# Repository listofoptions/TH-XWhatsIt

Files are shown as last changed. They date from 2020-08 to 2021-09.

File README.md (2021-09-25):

# TH-XWhatsIt

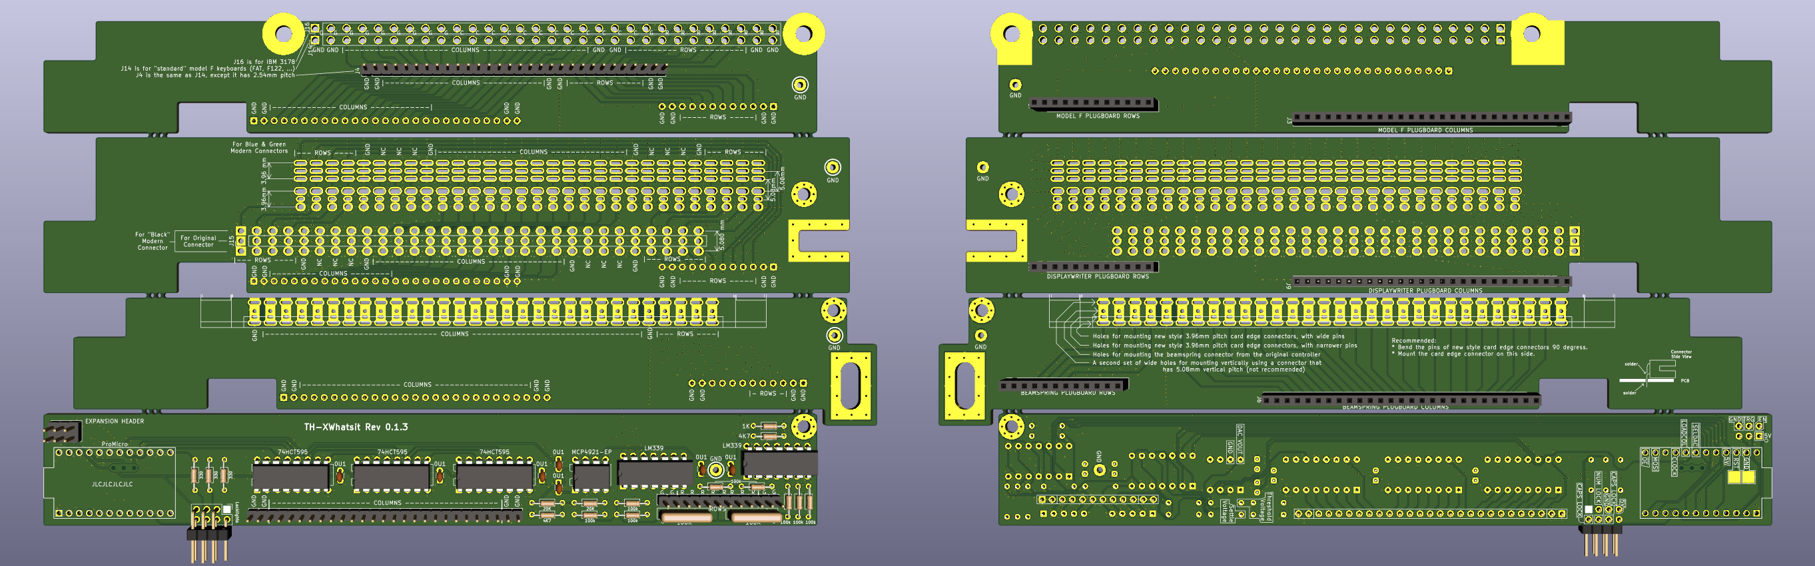
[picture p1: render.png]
Render of the mainboard, and of the plugboards, except the beamship plugboard


through hole implementation of the capsense controllers by XWhatsIt
(Tom Wong-Cornell). original liscencure holds, as well as CERN OSH
(compatible license).

original implementation of Tom Wong-Cornell's controller documented here

http://downloads.cornall.co/ibm-capsense-usb-web/ibm-capsense-usb.html

component documentation is supplied, working theory of operation is under
the previous link.

Please read the following files:

* [BOM.md](BOM.md) for Bill Of Materials.
* [ERRATA.md](ERRATA.md) for changes that must be made to older revision boards.
* [CHANGES.txt](CHANGES.txt) for all the detailed changes to this project over time.
* [PCB_ORDERING_INSTRUCTIONS.md](PCB_ORDERING_INSTRUCTIONS.md) for some notes on how to order PCBs.

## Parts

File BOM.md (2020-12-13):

# Bill Of Materials

## To build 1 pcs of the TH Xwhatsit controller Rev. 0.1.2, you need:

* 1pcs "Pro Micro 5V/16MHz" development board
    * 2pcs male 12-pin header (usually comes included with the Pro Micro)
* 1pcs MCP4921-EP DAC
* 2pcs LM339 comparator
    * (only 1pcs is really needed if the controller will only ever be used on <= 4-row keyboards, such as non-Displaywriter standard beamspring keyboards)
* 3pcs 74AHC595 or 74HCT595 or 74HC595 shift registers
    * (only 2pcs is really needed if the controller will only ever be used on <= 16-column keyboards, such as Model F of Displaywriter keyboards)
* 7pcs 100nF Through Hole Ceramic Capacitors (pin pitch is 2.54mm)
* 1pcs 1K through hole 0.25W resistor (better if subminiature type, metal film)
* 2pcs 20K through hole 0.25W resistors (better if subminiature type, metal film)
* 2pcs 4.7K through hole 0.25W resistors (better if subminiature type, metal film)
* 3pcs 330ohm through hole 0.25W resistors (better if subminiature type, metal film) (new in v0.1.2)
    * Optional if not using lock lights
* 100kohm Resistor Networks, or Resistors, two options:
    * These are recommended to be high precision (1% or 2%), but the design will likely work with 5% resistors too.
    * Option 1: 2pcs 100K 5-pin resistor networks
        * Make sure it's the kind that has a single common pin on one of the sides.
        * (only 1pcs is really needed if the controller will only ever be used on <= 4-row keyboards, such as non-Displaywriter standard beamspring keyboards)
    * Option 2: 8pcs 100K through hole 0.25W resistors (these are the resistors marked with ALT on the PCB)  (better if subminiature type, metal film)
        * (only 4pcs is really needed if the controller will only ever be used on <= 4-row keyboards, such as non-Displaywriter
* 3.96mm 30-pin card edge connectors (if using the controller for Beamspring/Displaywriter keyboards, and if you don't wish to desolder, and reuse the original connector from the original controller PCB)
* M3 standoff, screw, nut, and washers (optional, useful for better mechanical stability with daughterboards)
* 2.54 mm pitch through hole pin headers:
    * Optional if not using Solenoid/Expansion header:
        * 2x3-pin male pinheader (through-hole, can be vertical or 90-degree)
    * Optional if not using lock lights:
        * 2x4-pin male pinheader, (with 1 pin manually removed) (through-hole, can be vertical or 90-degree)
    * Optional if soldering wires directly to the motherboard, and not using the daughtercards:
        * male 27-pin pinheader (straight, through hole)
        * female 27-pin pinheader (straight, through hole)
        * male 12-pin pinheader (straight, through hole)
        * female 12-pin pinheader (straight, through hole)
    * You can buy pinheaders with more pins then necessary, and cut them. You can use two 1-row pin headers to make a vertical Solenoid connector.

## Notes regarding older revisions:

* Previous revisions can't fit an M3 standoff, so you have to get an M2 standoff
* Combining daughtercard/motherboard from different revisions is possible, (the pin headers are in the same relative positions), but the hole that can be used for a standoff is in a slightly different position, so if combining you can't use standoffs
* 10Kohm resistor networks, present in previous revisions are optional, they don't need to be mounted even if using a previous-revision board.
* the 10uF capacitor which was present in the first version of the TH MUST NOT be mounted.
* Only one pair of 1K, 4.7k resistors is necessary to set the BIAS voltage. Some previous TH versions had two pairs. It is okay to only mount one pair, or to mount both pairs, but the two bias points must be connected for >4-row keyboards.
* Previous versions supported fewer card edge connector types when using them for Beamspring/Displaywriter keyboards.

## Octopart BOM:

An octopart BOM has been assembled here: [link](https://octopart.com/bom-tool/UL7oTH6f)

## TME quick buy - uploading products from a file:

* [Go to this URL](https://www.tme.eu/ro/en/Profile/QuickBuy/load.html)
* Click "Uploading products from a file"
* Select "csv"
* Select [tme_bom.csv](tme_bom.csv) from this folder.
* Click Upload
* Click Add to Order
* Note: quantities have been adjusted for minimum order amounts.

## Individual links to various sources

All links in this document may become out of date. They may become unavailable, or price changes may make them not be good options anymore. Please do your own research before committing to buy.

* Pro Micro 5V/16MHz
    * Sparkfun Pro Micro: [link](https://www.sparkfun.com/products/12640)
        * More on the pricier side, but Sparkfun designed the Pro Micro, so they are probably the highest quality source.
        * They also have many distributors: [link](https://www.sparkfun.com/distributors)
          * The original Sparkfun Pro Micro is also available from these distributors:
            * Digikey: Digi-Key Part Number: [1568-1060-ND](https://www.digikey.com/en/products/detail/DEV-12640/1568-1060-ND/5140825)
            * Mouser: Mouser No: [474-DEV-12640](https://eu.mouser.com/ProductDetail/SparkFun/DEV-12640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)
    * Aliexpress:
        * There are many sellers on [aliexpress.com](https://www.aliexpress.com), the best deals are often for bulk quantities, but not always
        * Examples:
            * [link](https://www.aliexpress.com/item/4000087265549.html) (EDIT they recently raised their prices, cheaper may be available)
    * Ebay:
        * Also many sellers, examples:
            * [link](https://www.ebay.co.uk/itm/Pro-Micro-ATmega32U4-5V-16MHz-Replace-ATmega328-Pro-Mini-for-Arduino/283659748382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)
            * [link](https://www.ebay.co.uk/itm/Arduino-Pro-Micro-ATmega32U4-MU-5V-16MHz-Leonardo-Compatible-Board/183467795511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)
            * [link](https://www.ebay.co.uk/itm/Arduino-Pro-Micro-ATmega32U4-AU-5V-16MHz-Leonardo-Compatible-Board/183467793639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) - this is a less-then usual 'square' version where the microcontroller is in a TQFP package.
    * Alternatives, that are not exactly pro micro:
        * Sparkfun qwiic pro USB-C (not tested): [link](https://www.sparkfun.com/products/15795)
    * DO NOT BUY:
        * Don't buy 3V/8MHz Pro Micros, they are not supported.
        * Don't buy "DM DIY MORE" Pro Micros -- these are wider then most other pro micros, and won't physically fit [link](https://www.ebay.co.uk/itm/ATMEGA32U4-Pro-Micro-3-3V-5V-8-16MHz-USB-Controller-Board-Bootloader-for-Arduino/153425765054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)
        * Don't buy Proton-C, because non-AVR cores are not supported by my firmware. [link](https://qmk.fm/proton-c/)
        * *Maybe* do not buy Pro Micro drop-in replacements, that use DFU bootloader. These can be supported, but only if you compile your firmware locally. Otherwise many bootloader entry methods will not work. You also have the option of replacing the bootloader on one of these with ISP programming. Example: [Elite-C](https://keeb.io/products/elite-c-low-profile-version-usb-c-pro-micro-replacement-atmega32u4)
* Card Edge Connector (For beamsprings/displaywriters)
    * You can use the original connector, desoldered from the original controller
    * Please read this [thread](https://deskthority.net/viewtopic.php?f=7&t=24511&p=473024&hilit=tightness#p473024)
    * EDAC connector sources: (I recommend pin-modding these)
      * Higher pin-count, must be cut, but the extra pins are useful if pin-modding: 
        * Digikey: Digi-Key Part Number: [151-1359-ND](https://www.digikey.com/en/products/detail/307-086-520-202/151-1359-ND/1292373)
        * Mouser: Mouser No: [587-307-086-520-202](https://eu.mouser.com/ProductDetail/EDAC/307-086-520-202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)
      * TME: Not a great option, you can buy two of these lower-pin-count connectors, and cut both, and put them next to each other: TME Symbol: [307-030-520-202](https://www.tme.eu/ro/en/details/307-030-520-202/idc-connectors/edac/)
* MCP4921-E/P DAC:
    * TME: TME Symbol: [MCP4921-E/P](https://www.tme.eu/ro/en/details/mcp4921-e_p/d-a-converters-integrated-circuits/microchip-technology/)
    * LCSC: Last checked it wasn't available in a DIP package. 15 nov. 2020. LCSC Part # [C640392](https://lcsc.com/product-detail/Pre-ordered-Products_Microchip-Tech_MCP4921-E-P_Microchip-Tech-MCP4921-E-P_C640392.html)
    * Digikey: Digi-Key Part Number: [MCP4921-E/P-ND](https://www.digikey.com/en/products/detail/MCP4921-E-P/MCP4921-E-P-ND/716280)
    * Mouser: Mouser No: [579-MCP4921-E/P](https://eu.mouser.com/ProductDetail/Microchip-Technology/MCP4921-E-P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)
* 74*595 Shift Register:
    * TME: TME Symbol: [SN74HC595N](https://www.tme.eu/ro/en/details/sn74hc595n/shift-registers/texas-instruments/)
    * LCSC: LCSC Part # [C112387](https://lcsc.com/product-detail/74-Series_Wuxi-I-core-Elec-AIP74HC595-DIP_C112387.html)
    * Digikey: Digi-Key Part Number: [296-1600-5-ND](https://www.digikey.com/en/products/detail/texas-instruments/SN74HC595N/277246)
    * Mouser: Mouser No: [595-SN74HC595N](https://eu.mouser.com/ProductDetail/Texas-Instruments/SN74HC595N?qs=IEl3ej0IqwBTHkYa8XPoMQ%3D%3D)
* LM339 Comparator:
    * TME: TME Symbol: [LM339N/NOPB](https://www.tme.eu/ro/en/details/lm339n_nopb/tht-comparators/texas-instruments/)
    * LCSC: LCSC Part # [C127024](https://lcsc.com/product-detail/Analog-Comparators_UTC-Unisonic-Tech-LM339L-D14-T_C127024.html)
    * Digikey: Digi-Key Part Number: [296-39010-5-ND](https://www.digikey.com/en/products/detail/LM339N-NOPB/296-39010-5-ND/4733938)
    * Mouser: Mouser No: [926-LM339N/NOPB](https://eu.mouser.com/ProductDetail/Texas-Instruments/LM339N-NOPB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)
* 100nF Through Hole Ceramic Capacitors:
    * TME: TME Symbol: [CC-100N](https://www.tme.eu/ro/en/details/cc-100n/50v-tht-ceramic-capacitors/sr-passives/)
    * LCSC: LCSC Part # [C154503](https://lcsc.com/product-detail/Multilayer-Ceramic-Capacitors-MLCC-Leaded_FH-Guangdong-Fenghua-Advanced-Tech-CT4-0805Y104M500F1_C154503.html)
    * Digikey: Digi-Key Part Number: [399-4329-ND](https://www.digikey.com/en/products/detail/C322C104K5R5TA/399-4329-ND/818105)
    * Mouser: Mouser No: [80-C322C104K5R](https://eu.mouser.com/ProductDetail/KEMET/C322C104K5R5TA?qs=XvIqZs20p47gvrtGJkxvnw%3D%3D)
* 1K resistors:
    * TME variants:
      * TME Symbol: [M0.4W-1K](https://www.tme.eu/ro/en/details/m0.4w-1k/0-4w-metal-film-tht-resistors/royal-ohm/mff04ff1001a5/)
      * TME Symbol: [MF0204FTE52-1K](https://www.tme.eu/ro/en/details/mf0204fte52-1k/0-4w-metal-film-tht-resistors/yageo/mf0204fte52-1kl/)
      * TME Symbol: [MBA02040C1001FCT00](https://www.tme.eu/ro/en/details/mba02040c1001fct00/0-4w-metal-film-tht-resistors/vishay/)
      * TME Symbol: [MRS16000C1001FCT00](https://www.tme.eu/ro/en/details/mrs16000c1001fct00/0-4w-metal-film-tht-resistors/vishay/)
    * LCSC: LCSC Part # [C433503](https://lcsc.com/product-detail/Metal-Film-Resistor-TH_TyoHM-RN-1-8W-1K-F-T-B-A1_C433503.html)
    * Digikey: Digi-Key Part Number: [PPC1.00KXCT-ND](https://www.digikey.com/en/products/detail/SFR16S0001001FR500/PPC1.00KXCT-ND/594732)
    * Mouser: Mouser No: [594-SFR16S0001001FR5](https://eu.mouser.com/ProductDetail/Vishay-BC-Components/SFR16S0001001FR500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)
* 20K resistors:
    * TME variants:
      * TME Symbol: [MBA02040C2002FC100](https://www.tme.eu/ro/en/details/mba02040c2002fc100/0-4w-metal-film-tht-resistors/vishay/)
      * TME Symbol: [M0.4W-20K](https://www.tme.eu/ro/en/details/m0.4w-20k/0-4w-metal-film-tht-resistors/royal-ohm/mff04ff2002a5/)
    * LCSC: LCSC Part # [C433488](https://lcsc.com/product-detail/Metal-Film-Resistor-TH_TyoHM-RN-1-8W-20K-F-T-B-A1_C433488.html)
    * Digikey: Digi-Key Part Number: [PPC20.0KXCT-ND](https://www.digikey.com/en/products/detail/SFR16S0002002FR500/PPC20.0KXCT-ND/594752)
    * Mouser: Mouser No: [594-SFR16S0002002FR5](https://eu.mouser.com/ProductDetail/Vishay-BC-Components/SFR16S0002002FR500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)
* 4.7K resistors:
    * TME variants:
      * TME Symbol: [MBA02040C4701FCT00](https://www.tme.eu/ro/en/details/mba02040c4701fct00/0-4w-metal-film-tht-resistors/vishay/)
      * TME Symbol: [MF0204FTE52-4K7](https://www.tme.eu/ro/en/details/mf0204fte52-4k7/0-4w-metal-film-tht-resistors/yageo/mf0204fte52-4k7l/)
      * TME Symbol: [MRS16000C4701FC100](https://www.tme.eu/ro/en/details/mrs16000c4701fc100/0-4w-metal-film-tht-resistors/vishay/)
      * TME Symbol: [M0.4W-4K7](https://www.tme.eu/ro/en/details/m0.4w-4k7/0-4w-metal-film-tht-resistors/royal-ohm/mff04ff4701a5/)
    * LCSC: LCSC Part # [C433477](https://lcsc.com/product-detail/Metal-Film-Resistor-TH_TyoHM-RN-1-8W-4K7-F-T-B-A1_C433477.html)
    * Digikey: Digi-Key Part Number: [BC3275CT-ND](https://www.digikey.com/en/products/detail/MBA02040C4701FCT00/BC3275CT-ND/6138778)
    * Mouser: Mouser No: [594-5063JD4K700F5](https://eu.mouser.com/ProductDetail/Vishay-Beyschlag/MBA02040C4701FCT00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)
* 330ohm resistors:
    * TME variants:
      * TME Symbol: [MBA02040C3300FCT00](https://www.tme.eu/ro/en/details/mba02040c3300fct00/0-4w-metal-film-tht-resistors/vishay/)
      * TME Symbol: [MRS16000C3300FCT00](https://www.tme.eu/ro/en/details/mrs16000c3300fct00/0-4w-metal-film-tht-resistors/vishay/)
      * TME Symbol: [M0.4W-330R](https://www.tme.eu/ro/en/details/m0.4w-330r/0-4w-metal-film-tht-resistors/royal-ohm/mff04ff3300a50/)
    * LCSC: LCSC Part # [C433480](https://lcsc.com/product-detail/Metal-Film-Resistor-TH_TyoHM-RN-1-8W-330R-F-T-B-A1_C433480.html)
    * Digikey: Digi-Key Part Number: [BC3933CT-ND](https://www.digikey.com/en/products/detail/vishay-beyschlag-draloric-bc-components/MRS16000C3300FCT00/7351363)
    * Mouser: Mouser No: [594-5063JD330R0F](https://eu.mouser.com/ProductDetail/Vishay-Beyschlag/MBA02040C3300FC100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)
* 100kohm resistor networks (either get the resistor networks, or individual resistors, not both):
    * TME variants:
      * TME Symbol for 2% precision resistor network (was out of stock on 15 nov. 2020): [4605X-101-104LF](https://www.tme.eu/ro/en/details/4605x-101-104lf/tht-resistor-networks/bourns/)
      * TME Symbol for 2% precision resistor network: [DR100K-4/5](https://www.tme.eu/ro/en/details/dr100k-4_5/tht-resistor-networks/royal-ohm/rnla05g0104b0e/)
    * LCSC variants:
      * LCSC Symbol for 5% precision resistor network: [C11398](https://lcsc.com/product-detail/Resistor-Networks-Arrays_FH-Guangdong-Fenghua-Advanced-Tech-A05-104JP_C11398.html)
        * ^ This one is not really recommended, too low precision, it would probably work, but better find higher precision resistor network, or use individual resistors.
      * LCSC Symbol for 2% precision resistor network (was out of stock on 15 nov. 2020): [C353644](https://lcsc.com/product-detail/Resistor-Networks-Arrays-TH_ZHUHAI-MONEC-ELEC-RAA05104G_C353644.html)
* 100kohm individual resistors (either get the resistor networks, or individual resistors, not both):
    * TME variants:
      * TME Symbol for 1% precision individual resistors: [MBA02040C1003FCT00](https://www.tme.eu/ro/en/details/mba02040c1003fct00/0-4w-metal-film-tht-resistors/vishay/)
      * TME Symbol for 1% precision individual resistors: [MF0204FTE52-100K](https://www.tme.eu/ro/en/details/mf0204fte52-100k/0-4w-metal-film-tht-resistors/yageo/mf0204fte52-100kl/)
      * TME Symbol for 1% precision individual resistors: [M0.4W-100K](https://www.tme.eu/ro/en/details/m0.4w-100k/0-4w-metal-film-tht-resistors/royal-ohm/mff04ff1003a5/)
    * LCSC Symbol for 1% precision individual resistors: [C433501](https://lcsc.com/product-detail/Metal-Film-Resistor-TH_TyoHM-RN-1-8W-100K-F-T-B-A1_C433501.html)
    * Digikey: Digi-Key Part Number: [PPC100KXCT-ND](https://www.digikey.com/en/products/detail/SFR16S0001003FR500/PPC100KXCT-ND/594692)
    * Mouser: Mouser No: [594-SFR16S0001003FR5](https://eu.mouser.com/ProductDetail/Vishay-BC-Components/SFR16S0001003FR500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)
* M3 standoff/screw/washer:
    * TME:
        * 10mm M3 standoff: TME Symbol: [TFF-M3X10/DR113](https://www.tme.eu/ro/en/details/tff-m3x10_dr113/metal-spacers/dremec/113x10/)
        * 0.5mm height 6mm external diameter M3 washers to fine adjust spacing: TME Symbol: [B3/6/0.5/BN1976](https://www.tme.eu/ro/en/details/b3_6_0.5_bn1976/washers/bossard/m3-6-0-5-bn1976-din988/)
            * you will need to use two 0.5mm height washers, so the total height will be 10mm + 2*0.5mm = 11mm. This matches the total height of the plastic parts of the pin headers, which is 8.5mm + 2.5mm = 11mm.
        * 5mm long M3 screws: TME Symbol: [B3X5/BN2724](https://www.tme.eu/ro/en/details/b3x5_bn2724/screws/bossard/m3x5-bn2724/)
    * Digikey:
        * 11mm M3 standoff: Digi-Key Part Number: [732-10550-ND](https://www.digikey.com/en/products/detail/970110321/732-10550-ND/6174770)
        * Digi-Key Part Number: [36-9191-4-ND](https://www.digikey.com/en/products/detail/9191-4/36-9191-4-ND/4499485)
    * Mouser:
        * 11mm M3 standoff: Mouser No: [710-970110321](https://eu.mouser.com/ProductDetail/Wurth-Elektronik/970110321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)
        * Mouser No: [534-9191-4](https://eu.mouser.com/ProductDetail/Keystone-Electronics/9191-4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)
    * Aliexpres:
      * 910pcs/set M3 Male Female Hex Brass Standoff Spacer with Pan Head Screw Nut and Washer Assortment Kit: [link](https://www.aliexpress.com/item/4001179100363.html)
* Straight Vertical 40-pin male pinheader (will need to cut these, buy at least 2 40-pin ones):
    * TME: TME Symbol: [PH1-40-UA](https://www.tme.eu/ro/en/details/ph1-40-ua/pin-headers/adam-tech/)
    * LCSC: LCSC Part # [C429959](https://lcsc.com/product-detail/Pin-Header-Female-Header_JILN-12251140CNG0S115001_C429959.html)
    * Digikey: Digi-Key Part Number: [732-5334-ND](https://www.digikey.com/en/products/detail/61304011121/732-5334-ND/4846884)
    * Mouser: Mouser No: [710-61304011121](https://eu.mouser.com/ProductDetail/Wurth-Elektronik/61304011121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)
* Straight Vertical 40-pin female pinheader (will need to cut these, buy at least 2 40-pin ones):
    * TME: TME Symbol: [ZL262-40SG](https://www.tme.eu/ro/en/details/zl262-40sg/pin-headers/connfly/ds1023-1-40s21/)
    * LCSC: LCSC Part # [C429953](https://lcsc.com/product-detail/Pin-Header-Female-Header_JILN-22850140ANG1SYA01_C429953.html)
    * Digikey: Digi-Key Part Number: [HDR100IMP40F-G-V-TH-ND](https://www.digikey.com/en/products/detail/HDR100IMP40F-G-V-TH/HDR100IMP40F-G-V-TH-ND/5978200)
    * Mouser: Mouser No: [474-PRT-00115](https://eu.mouser.com/ProductDetail/SparkFun/PRT-00115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)
* 90degree/right-angle 2-row 2x40-pin male pinheader (will need to cut these):
    * TME: TME Symbol: [PH2RA-80-UA](https://www.tme.eu/ro/en/details/ph2ra-80-ua/pin-headers/adam-tech/)
    * LCSC: LCSC Part # [C358715](https://lcsc.com/product-detail/Pin-Header-Female-Header_MINTRON-MTP125-240R1_C358715.html)
    * Digikey: Digi-Key Part Number: [A106438-ND](https://www.digikey.com/en/products/detail/2-826634-0/A106438-ND/2276155)
    * Mouser: Mouser No: [571-2-826634-0](https://eu.mouser.com/ProductDetail/TE-Connectivity/2-826634-0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)
    * You can also use straight single-row pin headers from above, instead of 90-degree ones.

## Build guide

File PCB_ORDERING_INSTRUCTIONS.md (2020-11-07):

# PCB Ordering Instructions

## JLCPCB

* Issues with parsing the gerbers
    * Sometimes the gerber parsing servers are overloaded, and it will not parse immediately the gerber you uploaded. If this happens, you can still submit the order, but since board dimentions are not auto-calculated, the calculated price will be wrong, and that means that they will likely ask for an additional payment later on. If you want to avoid this, after uploading your gerbers, go to [file manager](https://cart.jlcpcb.com/fileManager), wait a little and refresh the page, until you see a thumbnail of the uploaded board, and then click the yellow "Quote" button. This time the PCB will load correctly.
* "Different Designs = 4"
    * JLCPCB policy considers each daughterboard a different design, see here: https://jlcpcb.com//quote/pcbOrderFaq/Different%20Design%20in%20Panel
    * They will "usually charge more" for this.
    * If when ordering, you select Different Designs: 4, they will always charge more, since price is autmoatically calculated. If you leave "Different Designs: 1", they might honor the order, they might put a hold on the fabrication and ask for additional payment, or they might modify the design of the breakoff mousebites, to make it easier for them to handle.
    * You can always generate new gerbers, with unneeded daughterboard removed.
* "Remove Order Number = Specify Location"
    * JLCPCB puts order numbers on the PCB silkscreen for tracking purposes. Asking them to remove this costs more, because it's harder to track the PCB. Specifying the location of this number doesn't cost more.
    * The latest revisions of the TH have the magic "JLCJLCJLCJLC" string underneath where the Pro Micro will go, so it's not an eyesore. For JLCPCB to make use of this, you have to specify "Remove Order Number = Specify Location". Otherwise they might not notice, and you will see the order number pop up somewhere else.

## Other PCB manufacturers

* You may want to remove the magic "JLCJLCJLCJLC" string from underneath the Pro Micro, if you are bothered by it, before ordering.

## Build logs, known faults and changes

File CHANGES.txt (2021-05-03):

January 31St, 2020:
    user: Listofoptions
        done:
            initial commit, completed main controller board and schematic
        todo:
            plugboard wiring and socket / connector positioning
            physical hardware testing
            firmware 
            firmware testing

Febuary 3rd, 2020
    user: Listofoptions
        done:
            moved setpoint decoupler cap to hopefully lower interferance with
            relatively high frequency output from the comparitors
            
            connector positioning for plugboard complete
            
            moved sense connector to allow better placement of corresponding
            socket on plugboards (sense traces needed more room on plugboards)
        todo:
            displaywriter plugboard wiring
            physical hardware testing
            firmware
            firmware testing
Febuary 4th, 2020
    user: listofoptions
        done:
            added ground strap points to plugboards, and positioned them to
            align with the ground strap on the main board
            
            displaywriter plugboard completely wired
            
            added cutouts in plugboards for expasion header wiring
        todo:
            maybe add more grounding straps to aid in mechanical strength
            (i intend to use metal standoffs to connect the plugboards and 
            main board)
            
            physical hardware testing
            firmware
            firmware testing
July 7th, 2020
    user: listofoptions
        done:
            removed capacitor on DAC output.
            ...?
August 22-23, 2020
    user: pandrew
        done:
            Cleanup of project structure
            Removed pull-ups from lm339 outputs. The atmega can supply internal pull-ups.
            Fixed missing connection to ground strap on main board
            Remove second set of biasing resistors (better for >4row keyboards)
            Made all resistors horizontally soldered
            Added option to use individual resistors instead of resistor networks. (Easier to source)
            Added pads to more easily short reset and GND.
            Use net tie to enforce star ground
            Thicken up ground traces
            Beamspring: Use new improved footprint
            Beamspring: added mounting hole
            Displaywriter: don't interfere with mounting plate, Add support for various vertical pin pitches, and for original connector.
            Displaywriter: Added support for using the mounting plate but only when using the original connector.
            Added Beamship plugboard to a separate subfolder. Not added to the default panel because it's too rare.
            Bumped revision to 0.0.3
            Added revision to silkscreen.
November 1, 2020 - Revision 0.1.1
    user: pandrew
        done:
            General:
                Made mounting hole bigger (M3). And moved it a little bit so it doesn't interfere with some components.
                Star ground turned into single ground.
                Ground fills added everywhere.
                Many stitching vias added everywhere.
                Added JLCJLCJLCJLC magic string under pro micro. When ordering from JLCPCB, you can select for Order Number: "Specify Location"
                Bumped version number to 0.1.1
                Added silkscreen to mark rows/columns everywhere.
                Added optional holes for soldering grounding wires everywhere.
            Controller:
                Added silkscreen to ease debugging, by marking various important nets.
                Rearranged some traces to maintain better separation between traces, and better ground reference.
            Model F plugboard:
                Modified 3.96mm pitch holes, to hole sizes and pad sizes that match original xwhatsit model F controller
                Moved 3.96mm pitch holes closer to the edge, so it doesn't interfere with case in F AT cases.
                Added mounting holes
                Added holes to support 3178 keyboards.
            Displaywriter:
                Addes support for more connector types. (The displaywriter daughterboard is now taller)
            Beamspring:
                Bugfix to a mistake that only affected people that ran update footprints from library.
            Beamship daughterboard:
                Added support for more connectors. Added breakoff-able mounting hole.
November 7, 2020
    user: pandrew
        done:
            Fix up revision number in PCB file title block. Revision was already correct in schematic and silkscreen.
            Added documentation: BOM.md, ERRATA.md, PCB_ORDERING_INSTRUCTIONS.md
November 15, 2020
    user: pandrew
        done:
            BOM: changed TME examples from carbon film resistors to metal film resistors
            BOM: reformatted some links
            BOM: recommendation that 100k resistors/resistor networks should be high precision.
            BOM: added LCSC examples
            BOM: added Aliexpress M3 standoff/screw/nut/washer/... kit
            BOM: added digikey and mouser items
            BOM: added link to octopart.com bom
            BOM: added tme bom csv, and guide how to upload
December 13, 2020 - Revision 0.1.2
    user: pandrew
        done:
            Made left side of all plugboards 1.5mm shorter (the cutout for the solenoid header is 1.5mm bigger)
                this makes some connectors fit more comfortably
            Bumped revision number
December 13, 2020 - Revision 0.1.3
    user: pandrew
        done:
            Added locklights header (this lengthens the controller a little bit, and added cutouts to the daughtercards too.)
            Bumped revision number
December 13, 2020
    user: pandrew
        done:
            Updated BOM.
January 26, 2021
    user: pandrew
        done:
            Beamship Plugboard -- added extra grounding hole.
May 3, 2021
    user: pandrew
        done:
            Updated Pro Micro schematic symbol, fixed incorrect pin names, and made it a bit more verbose.
            Added schematics for various revisions, using the corrected Pro Micro symbol.
            Updated version numbers in errata.

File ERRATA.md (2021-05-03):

# Errata

This document only describes what changes must be made to each revision for it to function correctly.
For a full list of changes, please see CHANGES.txt

## Revision >= 0.1.1 (Rev. 0.1.1 on silkscreen) (released 2020/nov/01)
Git hash: 9028ddaa2e20d55d37fc6f7d3809adf717919eb1  
Schematic rev. was bumped to 0.1.1, PCB file revision was forgotten at 0.0.3  
please consider only git hash or revision that is mentioned on silkscreen for accurate revision identification.  
Generated gerbers are available on github, and deskthority.

* No known electrical issues

## Revision 0.0.3 - Third Version (Rev. 0.0.3 on silkscreen)
Git hash: 43d1e00e14cc144690cdfa7ccc7437dce1b8cad1  
Schematic rev. was bumped to 0.0.3, PCB file revision is 0.0.3, please consider only git hash or revision that is mentioned on silkscreen for accurate revision identification.  
Gerbers were never publicly available for this revision, only the Kicad project file.

* No known electrical issues

## Revision 0.0.3 - Second Version (Revision not mentioned on silkscreen)
Git hash: dcde7c1d5b266a0c9a05951c770276cc73248615  
Schematic rev. is 0.0.2, PCB file revision is 0.0.3, please consider only git hash for accurate revision identification.  
Gerbers were never publicly available for this revision, only the Kicad project file.

* This revision has separate BIAS voltages for each group of 4 rows. If the connected keyboard uses more than 4 rows, or if if uses some rows from the left 4 and some from the right 4, then the two BIAS points must be shorted together. One pair of biasing 1K/4.7K resistors are optional.
* 10K resistor networks are optional. (But only with recent enough firmware, that enables internal pull-up resistors in the microcontroller)
* The ground strap mounting hole on the controller is not grounded.

## Revision 0.0.3 - First Version (Revision not mentioned on silkscreen)
Git hash: 91dc5f78a520dae1363f0ed9b2873a4988be1632  
Schematic rev. is 0.0.2, PCB file revision is 0.0.3, please consider only git hash for accurate revision identification.  
This is the first revision that was known to be built by anyone,  
Gerbers were available from Deskthority.

* MUST NOT mount 10uF capacitor
* This revision has separate BIAS voltages for each group of 4 rows. If the connected keyboard uses more than 4 rows, or if if uses some rows from the left 4 and some from the right 4, then the two BIAS points must be shorted together. One pair of biasing 1K/4.7K resistors are optional.
* 10K resistor networks are optional. (But only with recent enough firmware, that enables internal pull-up resistors in the microcontroller)

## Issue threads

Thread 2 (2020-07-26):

Couple of suggestions

frogmaster, 2020-07-26:
Would have done a pull request, but kicad library management was driving me nuts.

As model F AT has soldered ribbon cable with 3.96mm pitch, add optional pads, connected 1-to-1 to existing plugboard connector. Positioning is important in horizontal direction as AT case has molded screw mount near there. The distance from the edge of the board to edge of pads shoult no exceed 16mm.  See the attached screenshot.

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

Also, the ground strap connector hole is annoyingly small, dealing with 2mm screws and standoffs is just painful. Maybe increase the hole size from 2.2mm to 3.5.

listofoptions, 2020-08-14:
we've got a branch working on this, and a few other issues that where brought to mind, so the next revision will fix this

listofoptions, 2020-08-24:
@frogmaster check the repo now, @purdeaandrei has done some major rework instead.

frogmaster, 2020-08-24:
Better. Although, the tiny mounting hole is still there, i would use 3.5mm hole for mounting with 3mm standoffs, if there's not a particular reason for the tiny one.

Still, i will probably design a single board specially for model f at with mounting holes in same places as the ibm board, and incorporate the changes made by Andrei into that. The double layer plugboard and elongated design just doesn't fit that particular keyboard very well. I will not do so soon though, as it's gotten a little busy at work.

purdeaandrei, 2020-11-07:
I believe the latest revision solves all of these problems, so we can close this issue.

By the way @frogmaster , nice work on the Model F-specific adaptation!

Andrei

purdeaandrei, 2020-11-15:
@frogmaster Closing this issue, please re-open if you think something has not been addressed adequately.

Closed 2020-11-15.

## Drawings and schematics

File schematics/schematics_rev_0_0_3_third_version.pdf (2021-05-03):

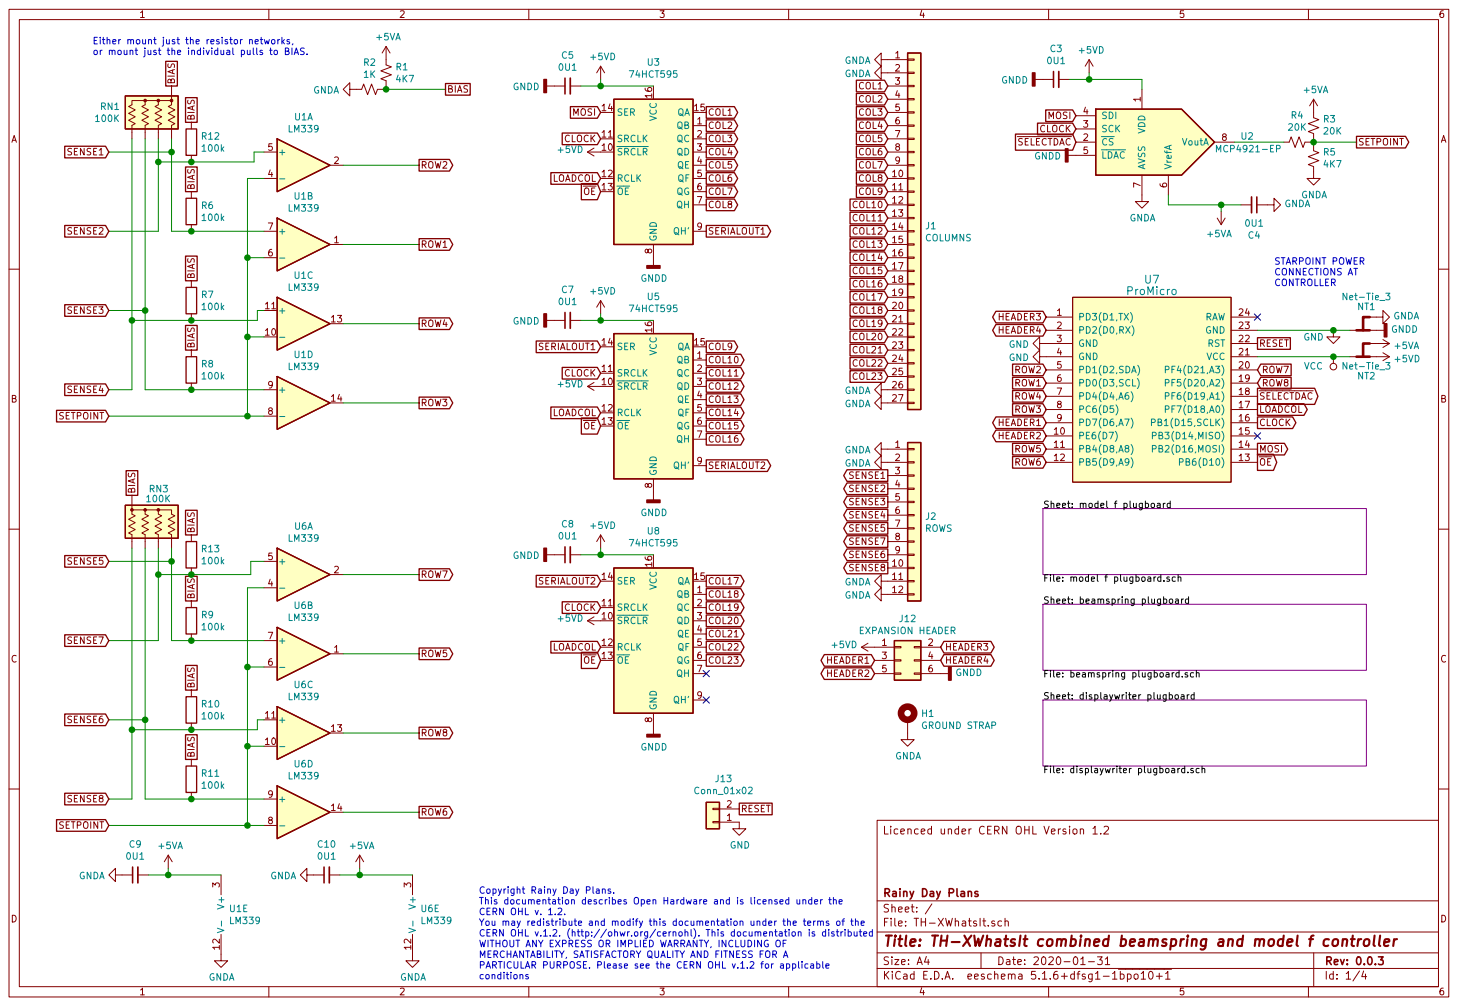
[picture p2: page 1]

Either mount just the resistor networks,
or mount just the individual pulls to BIAS.

7 VoutA 8 U2 MCP4921-EP GNDD GNDD GNDD GNDD GNDD

HEADER2 Copyright Rainy Day Plans.

File: model f plugboard.sch

File: beamspring plugboard.sch

File: displaywriter plugboard.sch

Id: 1/4 Title: TH-XWhatsIt combined beamspring and model f controller File: TH-XWhatsIt.sch Sheet: / Rainy Day Plans

This documentation describes Open Hardware and is licensed under the CERN OHL v. 1.2. You may redistribute and modify this documentation under the terms of the

CERN OHL v.1.2. (http://ohwr.org/cernohl). This documentation is distributed WITHOUT ANY EXPRESS OR IMPLIED WARRANTY, INCLUDING OF MERCHANTABILITY, SATISFACTORY QUALITY AND FITNESS FOR A

PARTICULAR PURPOSE. Please see the CERN OHL v.1.2 for applicable
conditions

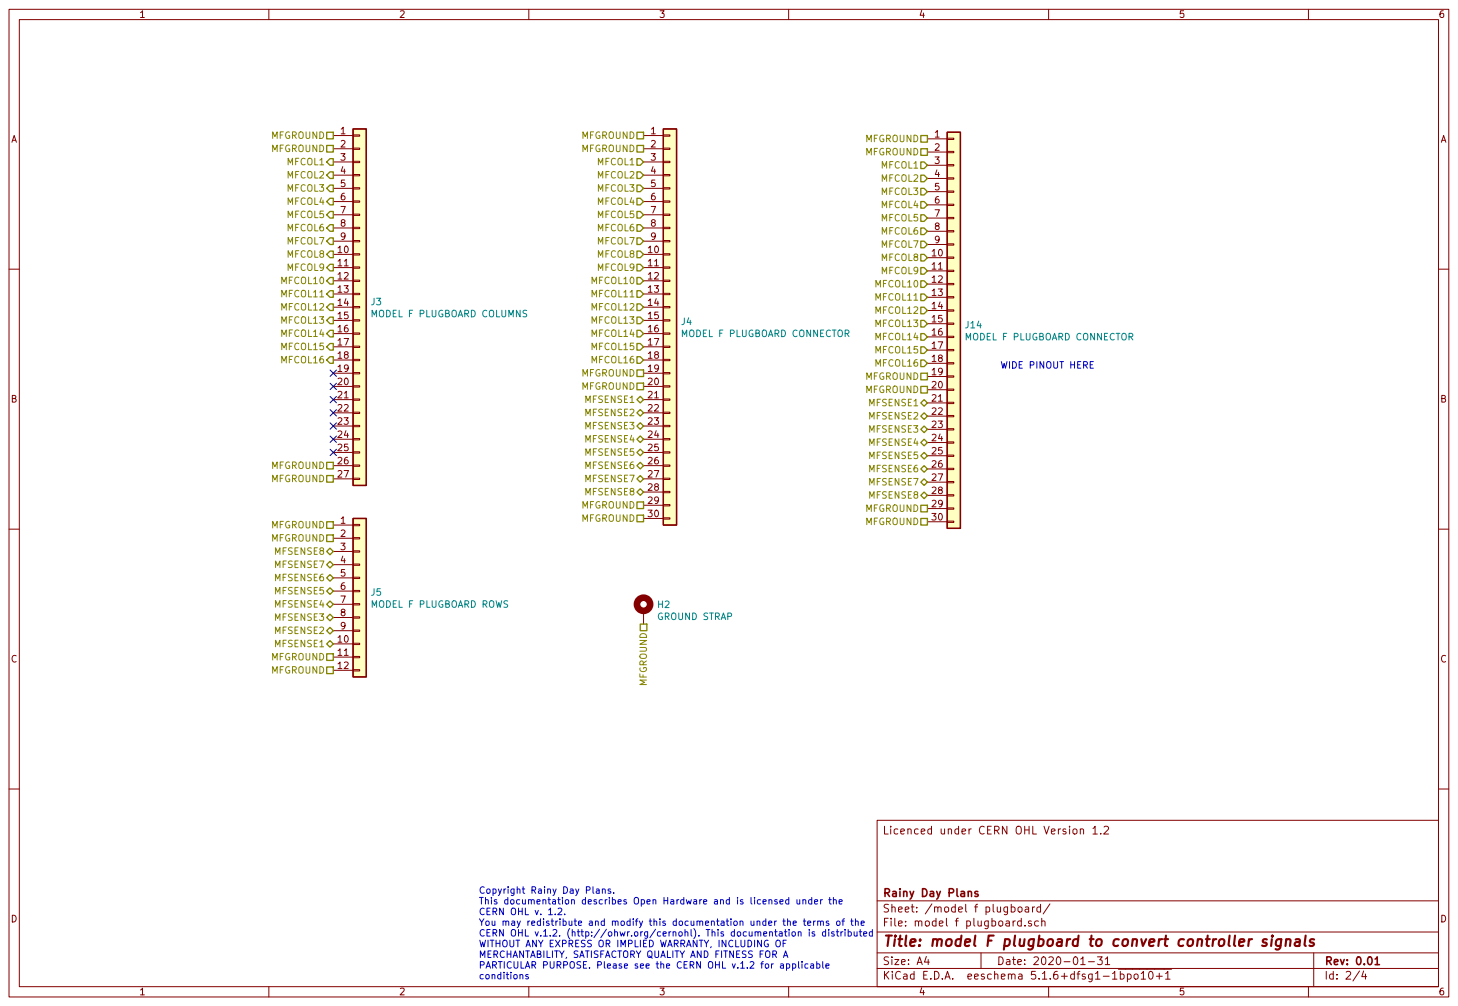
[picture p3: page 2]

Licenced under CERN OHL Version 1.2

Rainy Day Plans
Sheet: /model f plugboard/
File: model f plugboard.sch
Id: 2/4 Title: model F plugboard to convert controller signals

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

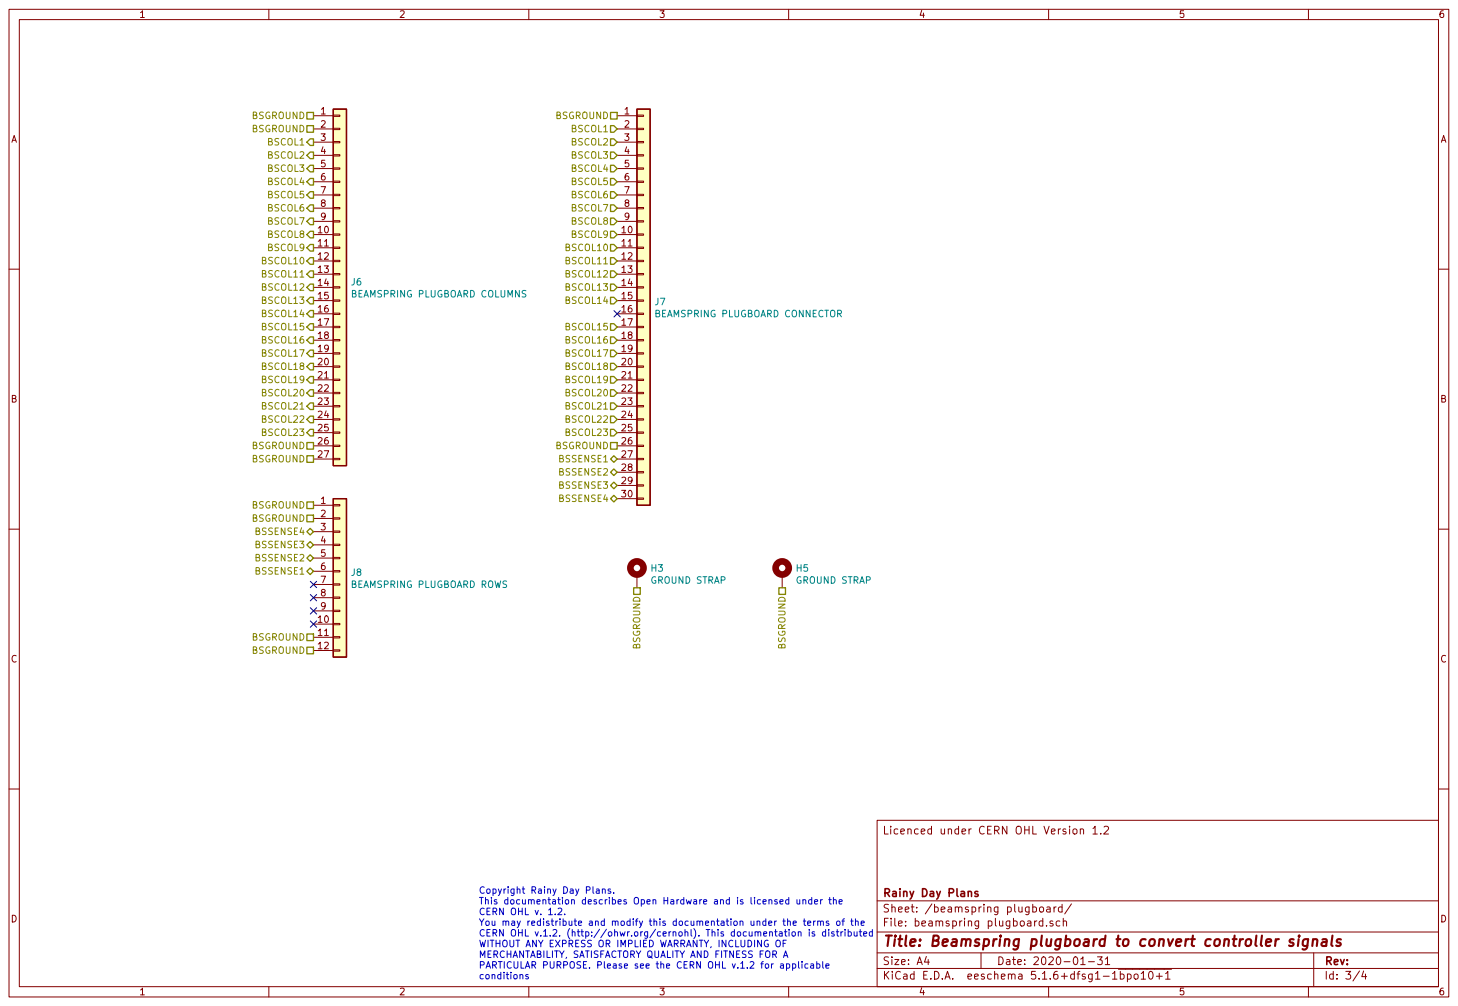
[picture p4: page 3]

Licenced under CERN OHL Version 1.2

Rainy Day Plans
Sheet: /beamspring plugboard/
File: beamspring plugboard.sch
Id: 3/4 Title: Beamspring plugboard to convert controller signals

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

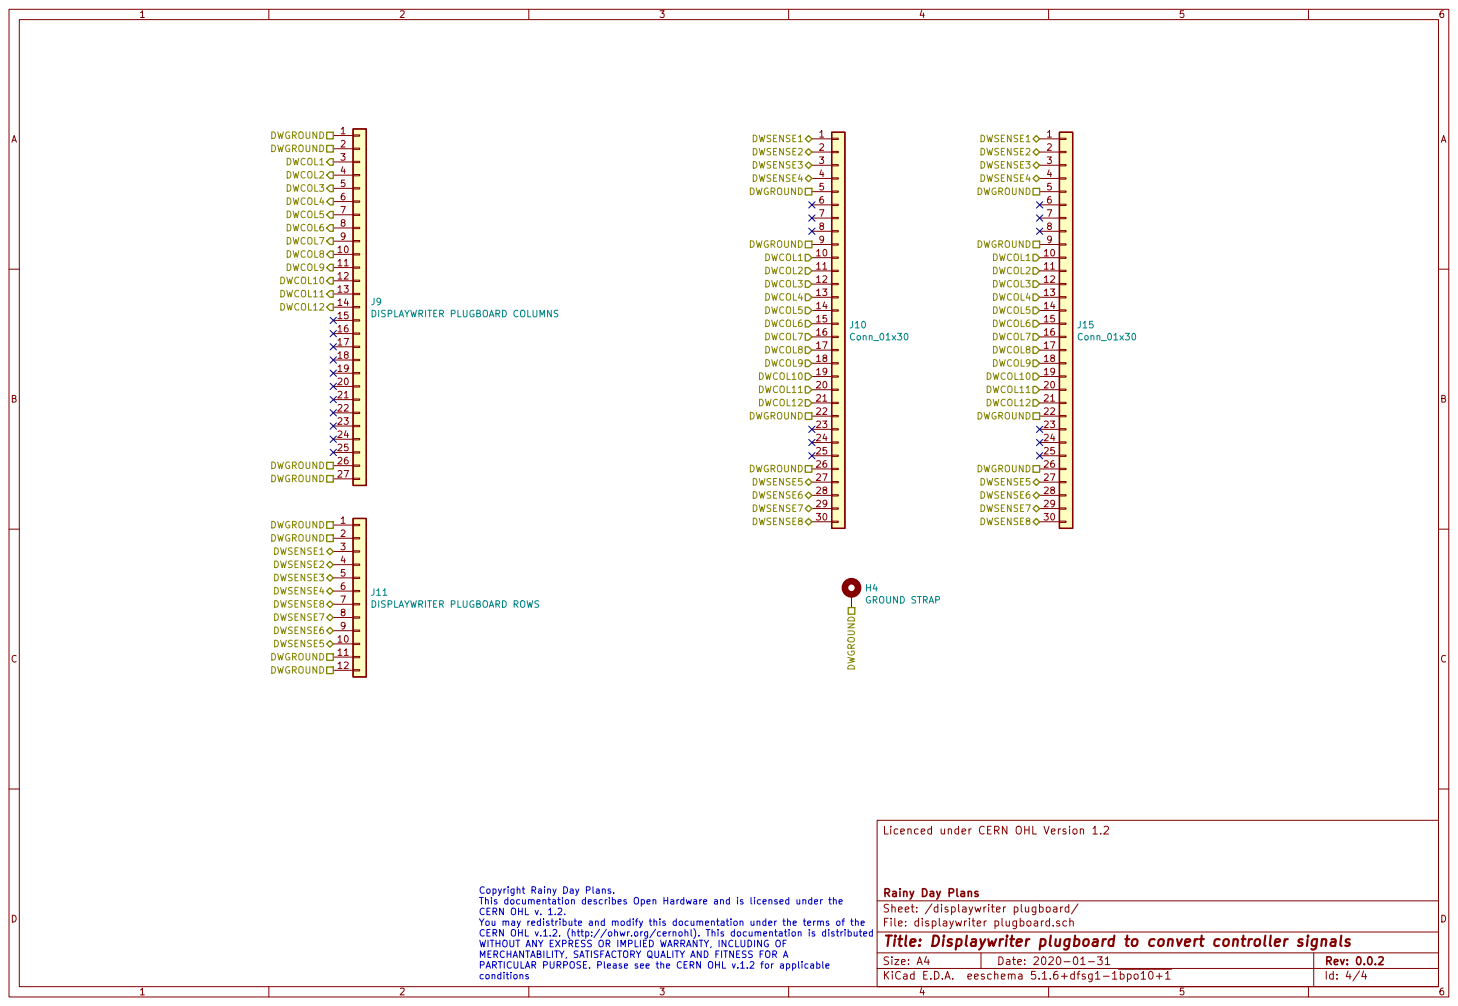
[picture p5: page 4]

Licenced under CERN OHL Version 1.2

Rainy Day Plans
Sheet: /displaywriter plugboard/
File: displaywriter plugboard.sch
Id: 4/4 Title: Displaywriter plugboard to convert controller signals

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

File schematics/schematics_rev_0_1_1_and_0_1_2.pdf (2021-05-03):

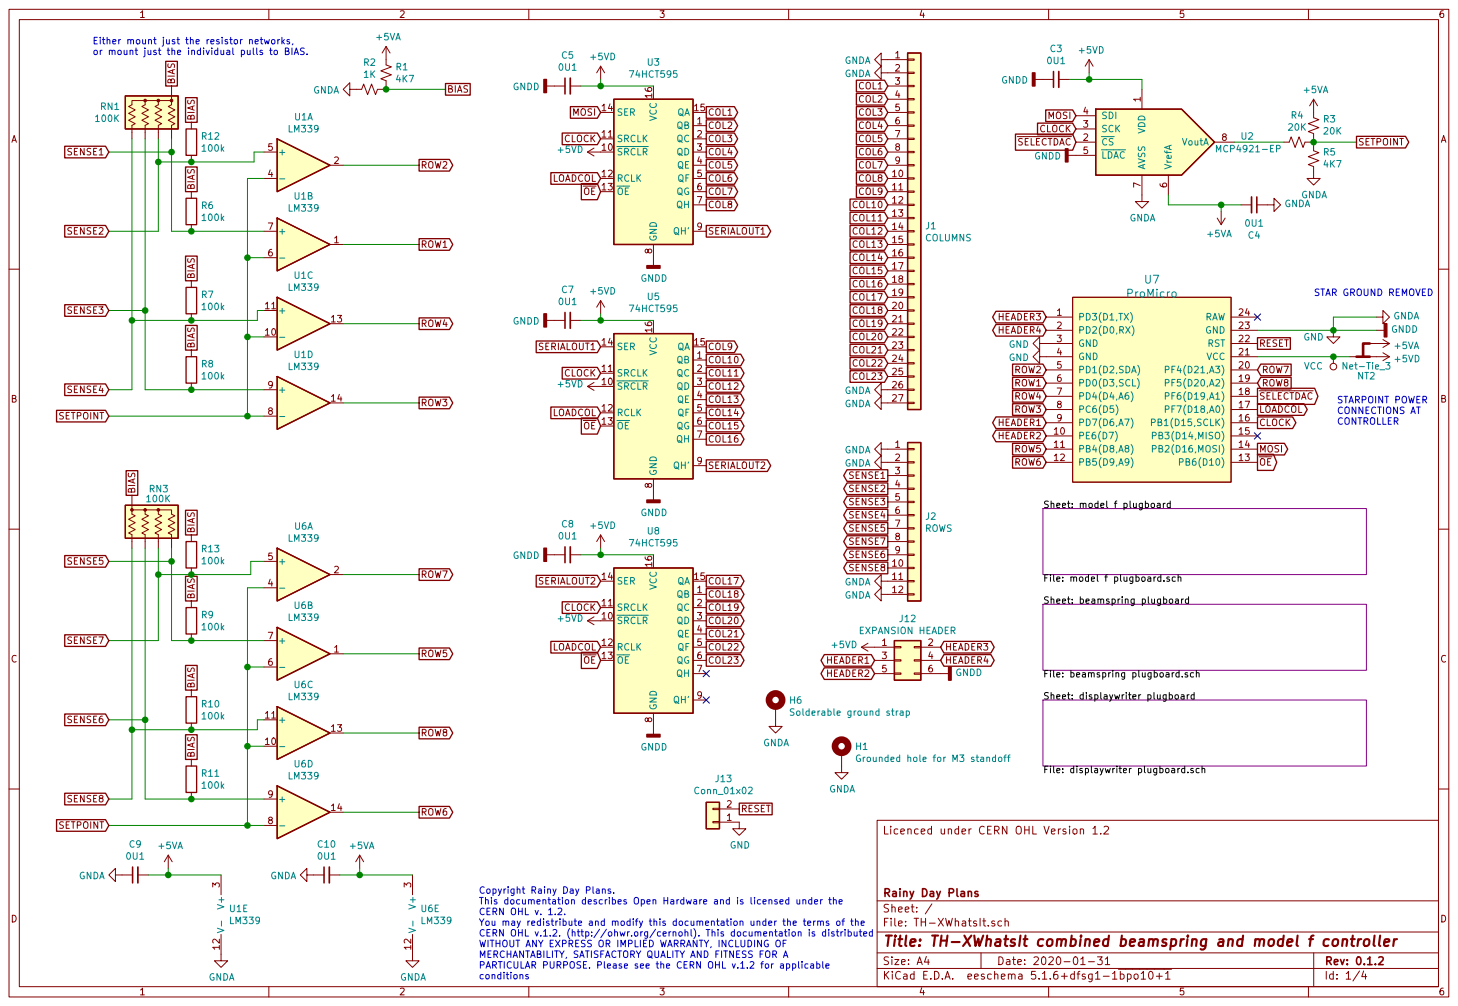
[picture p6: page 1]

Either mount just the resistor networks,
or mount just the individual pulls to BIAS.

RESET BIAS BIAS BIAS BIAS BIAS BIAS BIAS BIAS

VCC GND GND GND

File: model f plugboard.sch

J12 EXPANSION HEADER GNDAH1Grounded hole for M3 standoff

File: beamspring plugboard.sch

File: displaywriter plugboard.sch

Copyright Rainy Day Plans.
This documentation describes Open Hardware and is licensed under the CERN OHL v. 1.2. You may redistribute and modify this documentation under the terms of the

Id: 1/4 Title: TH-XWhatsIt combined beamspring and model f controller File: TH-XWhatsIt.sch Sheet: / Rainy Day Plans

CERN OHL v.1.2. (http://ohwr.org/cernohl). This documentation is distributed WITHOUT ANY EXPRESS OR IMPLIED WARRANTY, INCLUDING OF MERCHANTABILITY, SATISFACTORY QUALITY AND FITNESS FOR A

PARTICULAR PURPOSE. Please see the CERN OHL v.1.2 for applicable
conditions

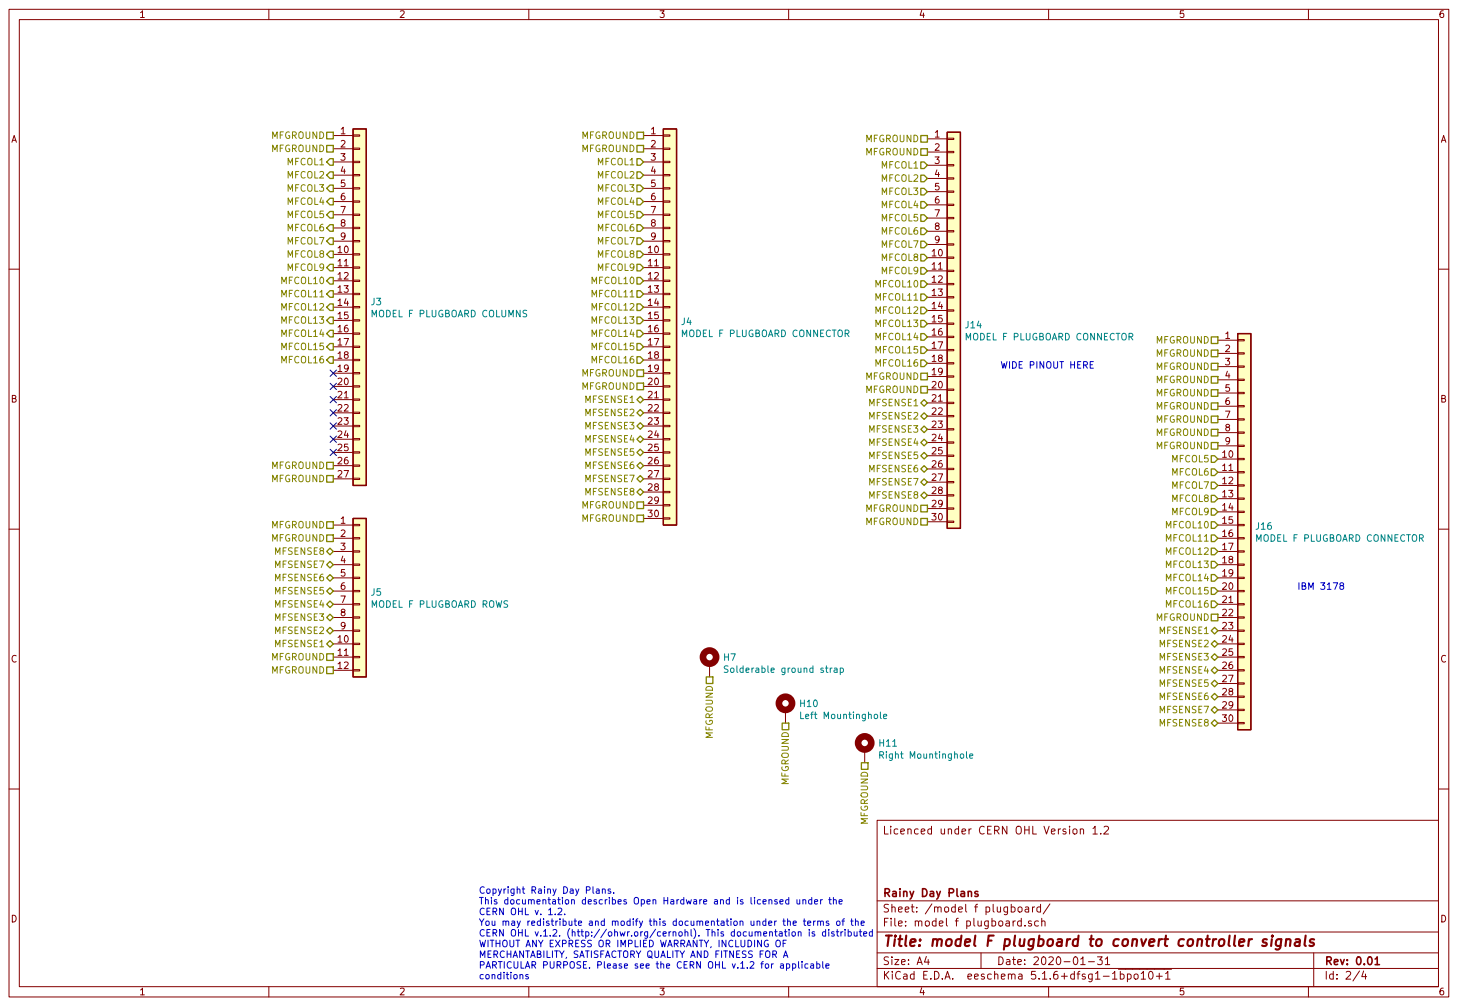
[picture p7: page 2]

IBM 3178 WIDE PINOUT HERE

Licenced under CERN OHL Version 1.2 1

Rainy Day Plans
Sheet: /model f plugboard/
File: model f plugboard.sch
Id: 2/4 Title: model F plugboard to convert controller signals

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

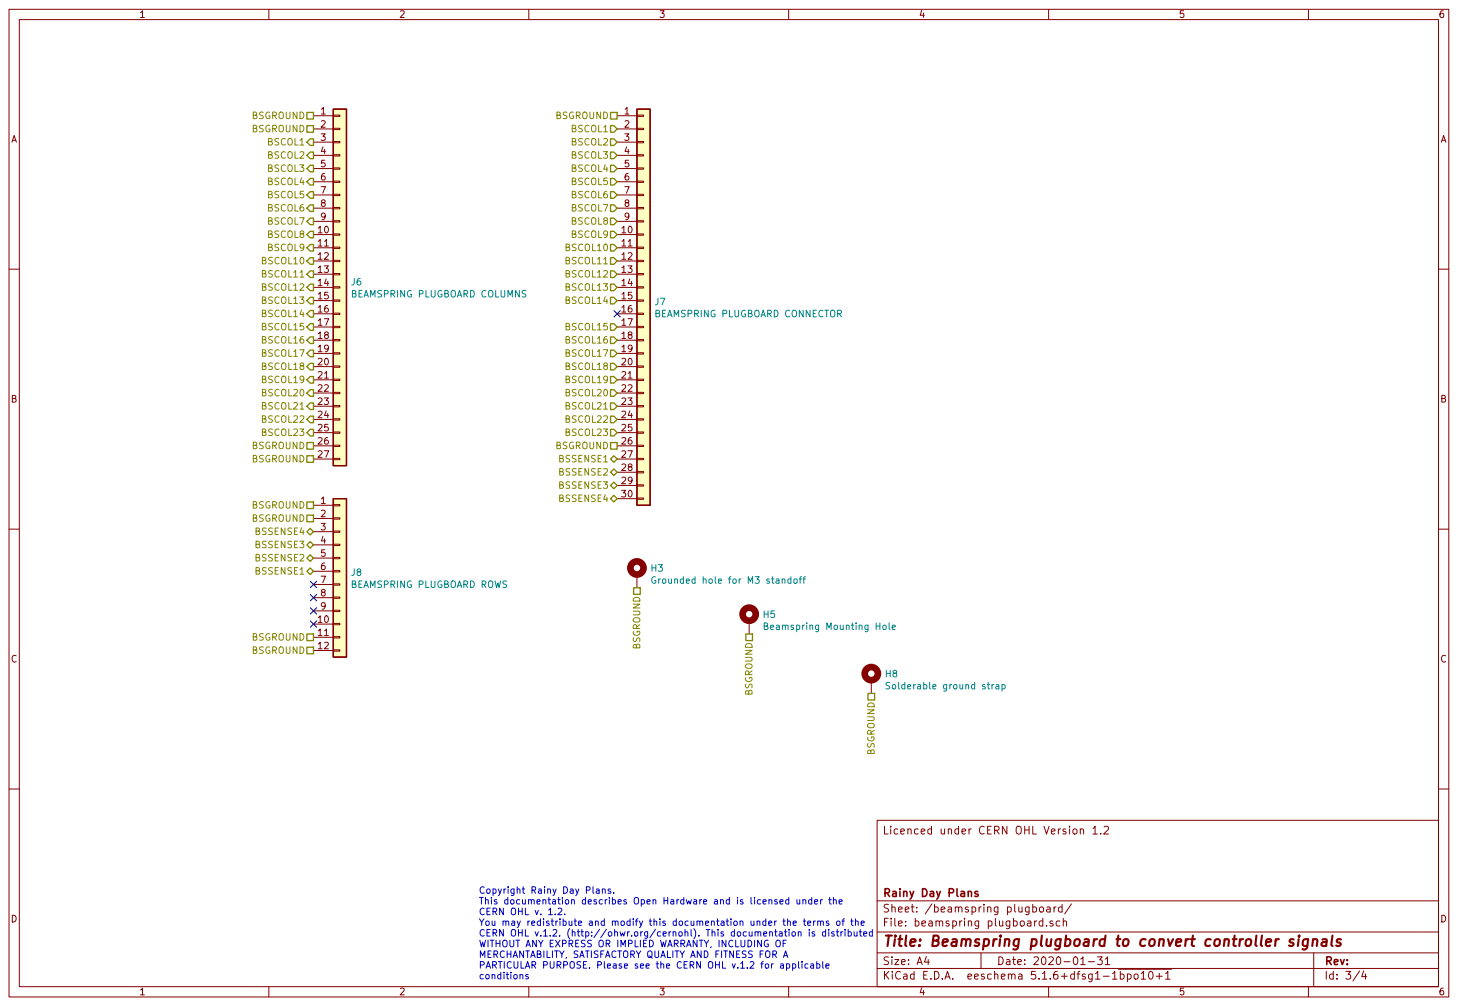
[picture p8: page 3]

Licenced under CERN OHL Version 1.2

Rainy Day Plans
Sheet: /beamspring plugboard/
File: beamspring plugboard.sch
Id: 3/4 Title: Beamspring plugboard to convert controller signals

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

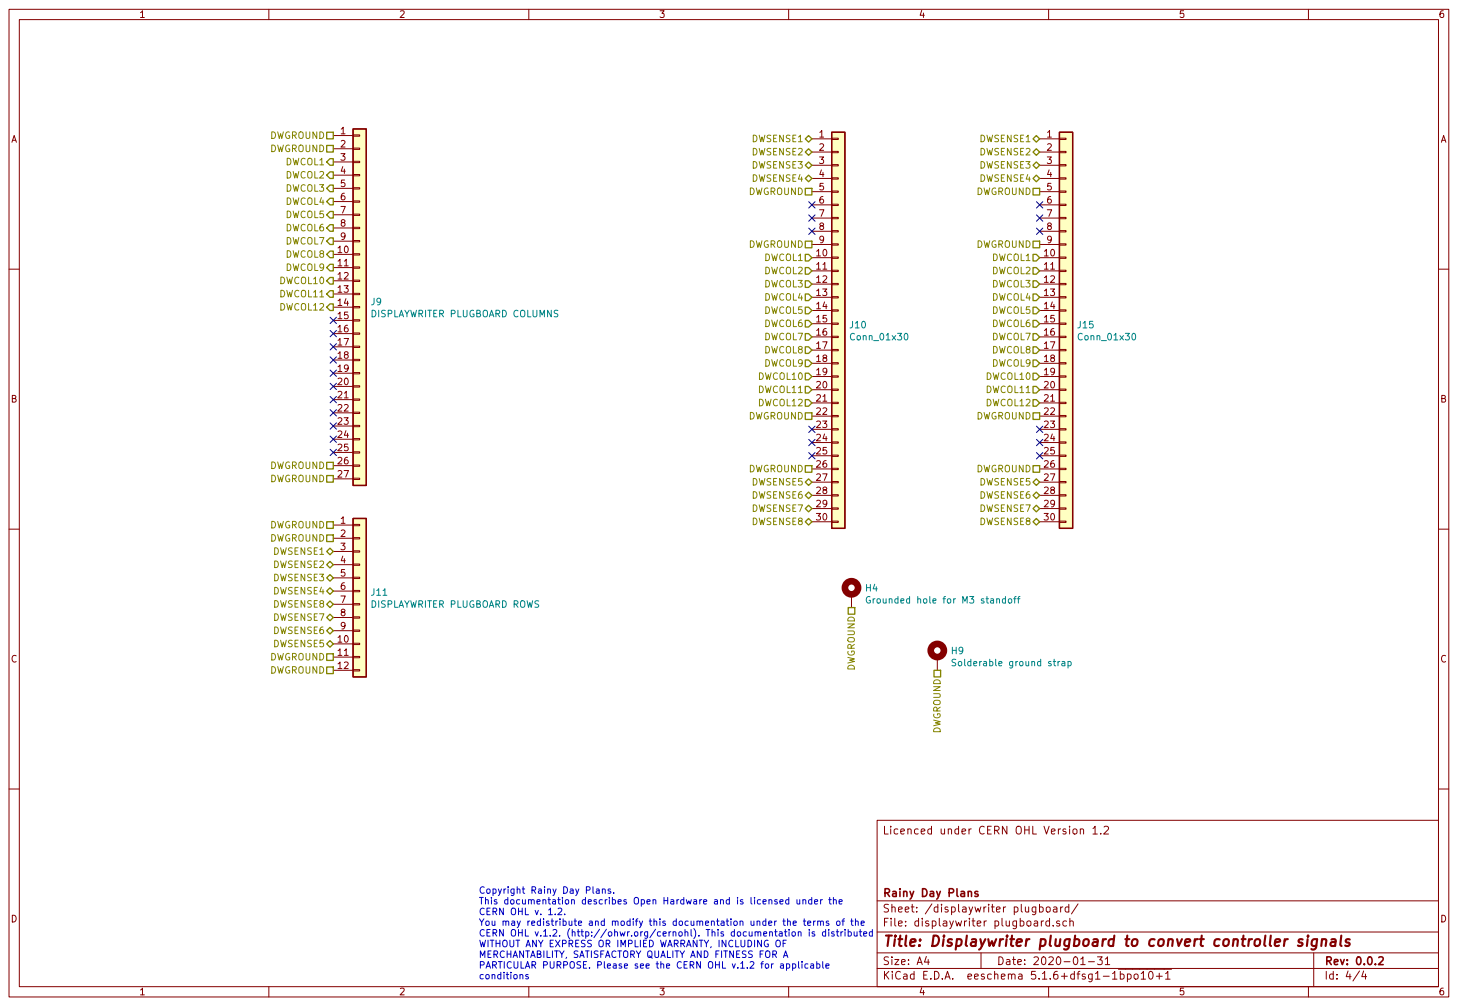
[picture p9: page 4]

Licenced under CERN OHL Version 1.2

Rainy Day Plans
Sheet: /displaywriter plugboard/
File: displaywriter plugboard.sch
Id: 4/4 Title: Displaywriter plugboard to convert controller signals

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

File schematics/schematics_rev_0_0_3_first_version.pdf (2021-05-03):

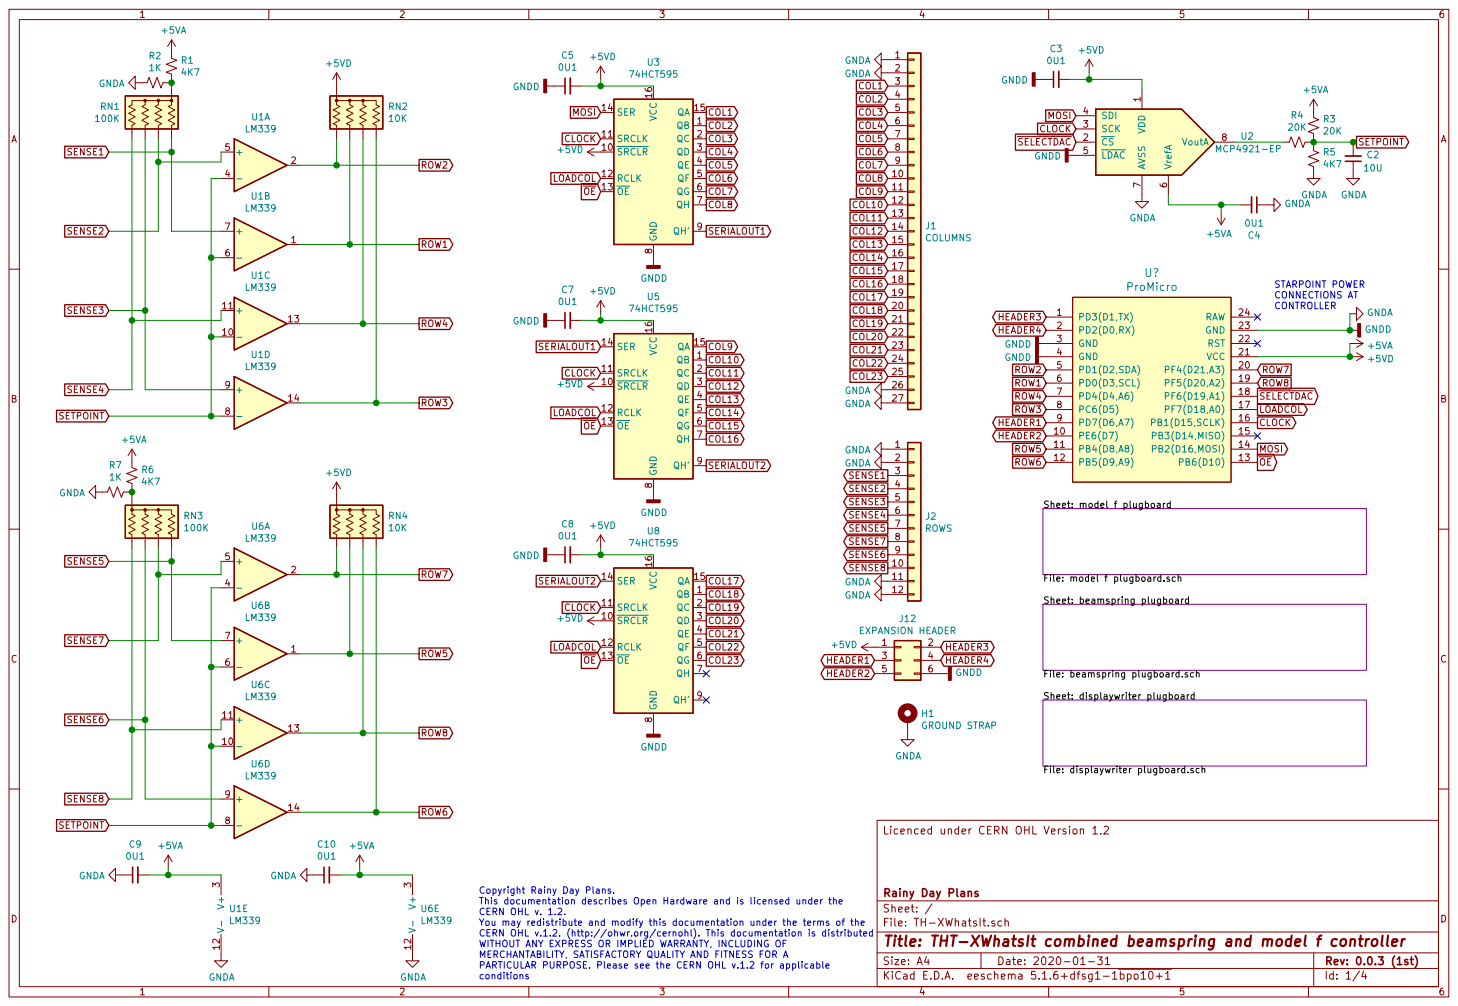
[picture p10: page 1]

File: model f plugboard.sch

File: beamspring plugboard.sch

File: displaywriter plugboard.sch +5VA

Copyright Rainy Day Plans.
This documentation describes Open Hardware and is licensed under the CERN OHL v. 1.2. You may redistribute and modify this documentation under the terms of the

Id: 1/4 Title: THT-XWhatsIt combined beamspring and model f controller File: TH-XWhatsIt.sch Sheet: / Rainy Day Plans

CERN OHL v.1.2. (http://ohwr.org/cernohl). This documentation is distributed WITHOUT ANY EXPRESS OR IMPLIED WARRANTY, INCLUDING OF MERCHANTABILITY, SATISFACTORY QUALITY AND FITNESS FOR A

PARTICULAR PURPOSE. Please see the CERN OHL v.1.2 for applicable
conditions

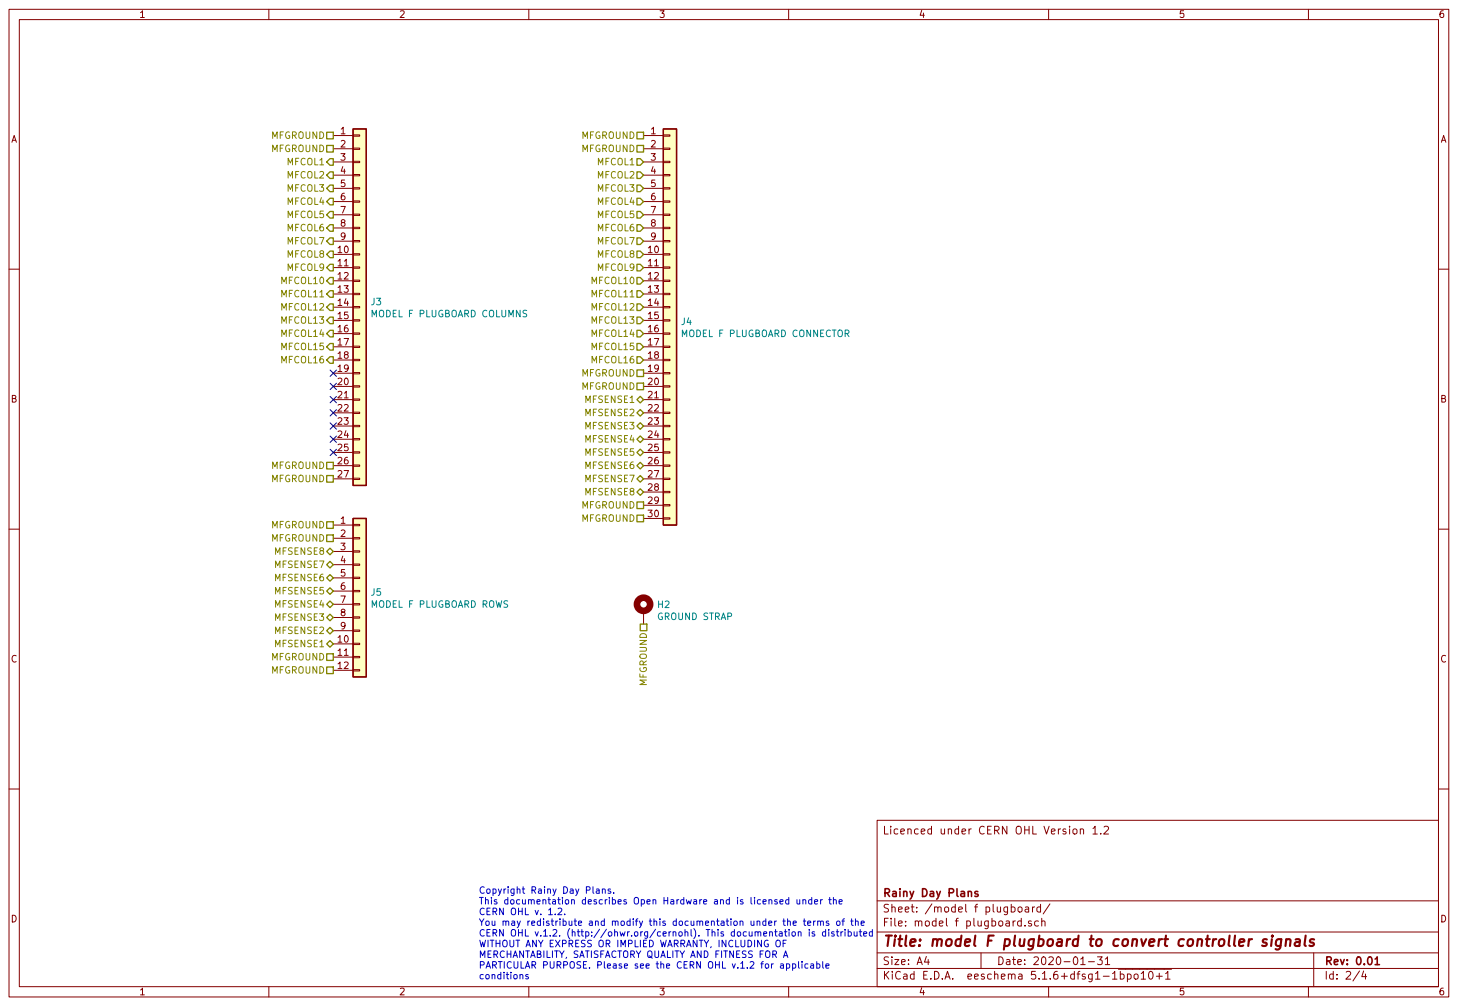
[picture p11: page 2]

Licenced under CERN OHL Version 1.2

Rainy Day Plans
Sheet: /model f plugboard/
File: model f plugboard.sch
Id: 2/4 Title: model F plugboard to convert controller signals

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

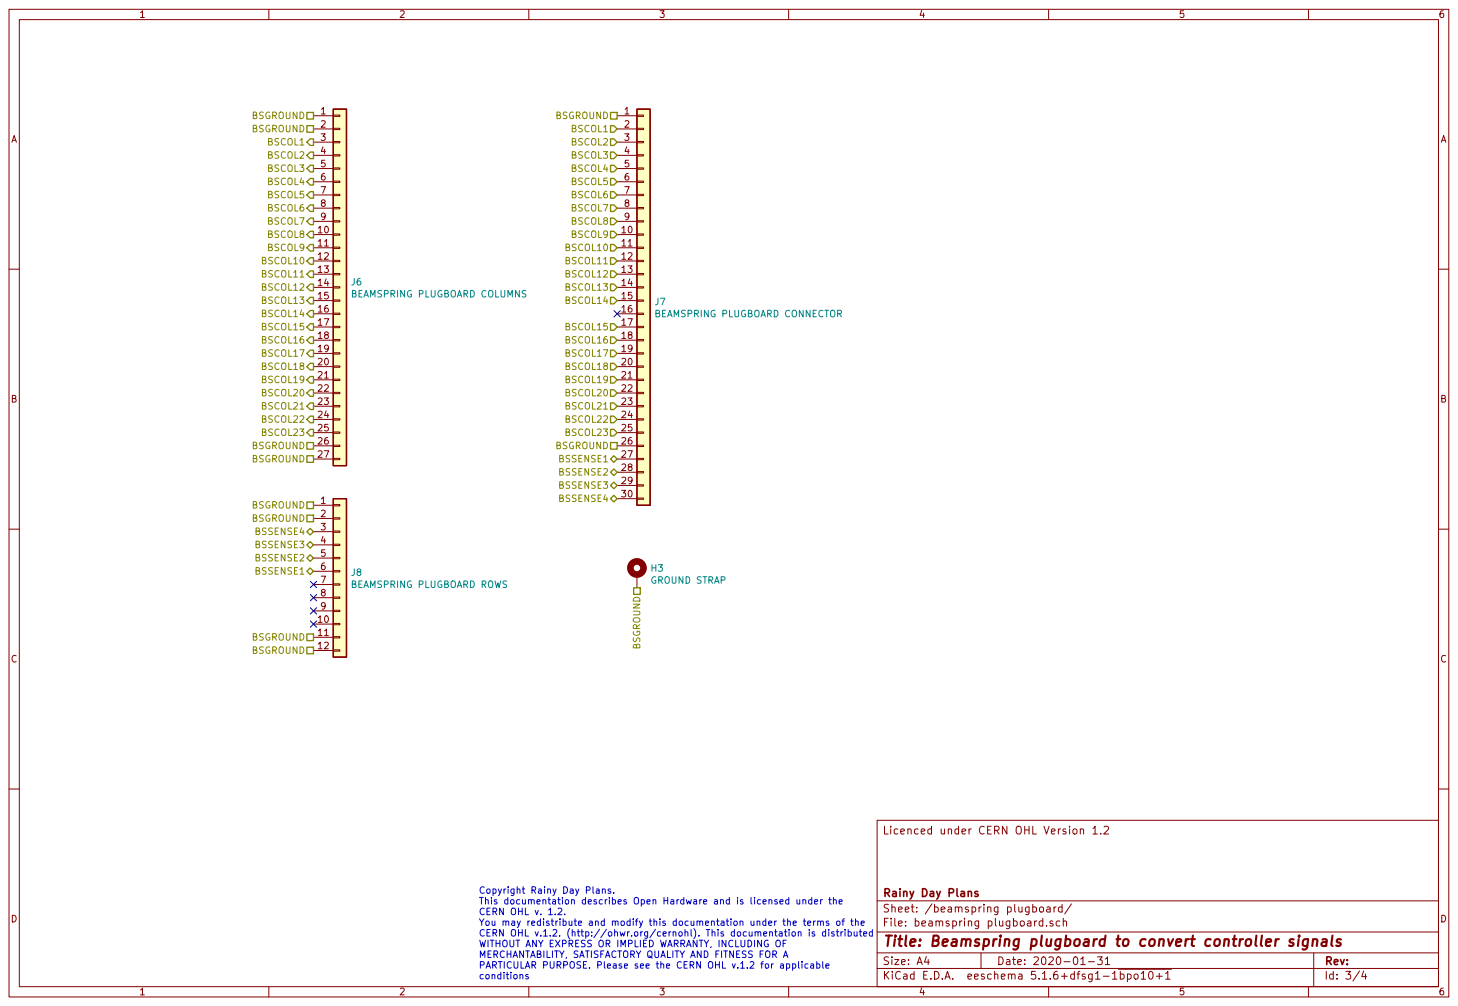
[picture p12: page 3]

Licenced under CERN OHL Version 1.2

Rainy Day Plans
Sheet: /beamspring plugboard/
File: beamspring plugboard.sch
Id: 3/4 Title: Beamspring plugboard to convert controller signals

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

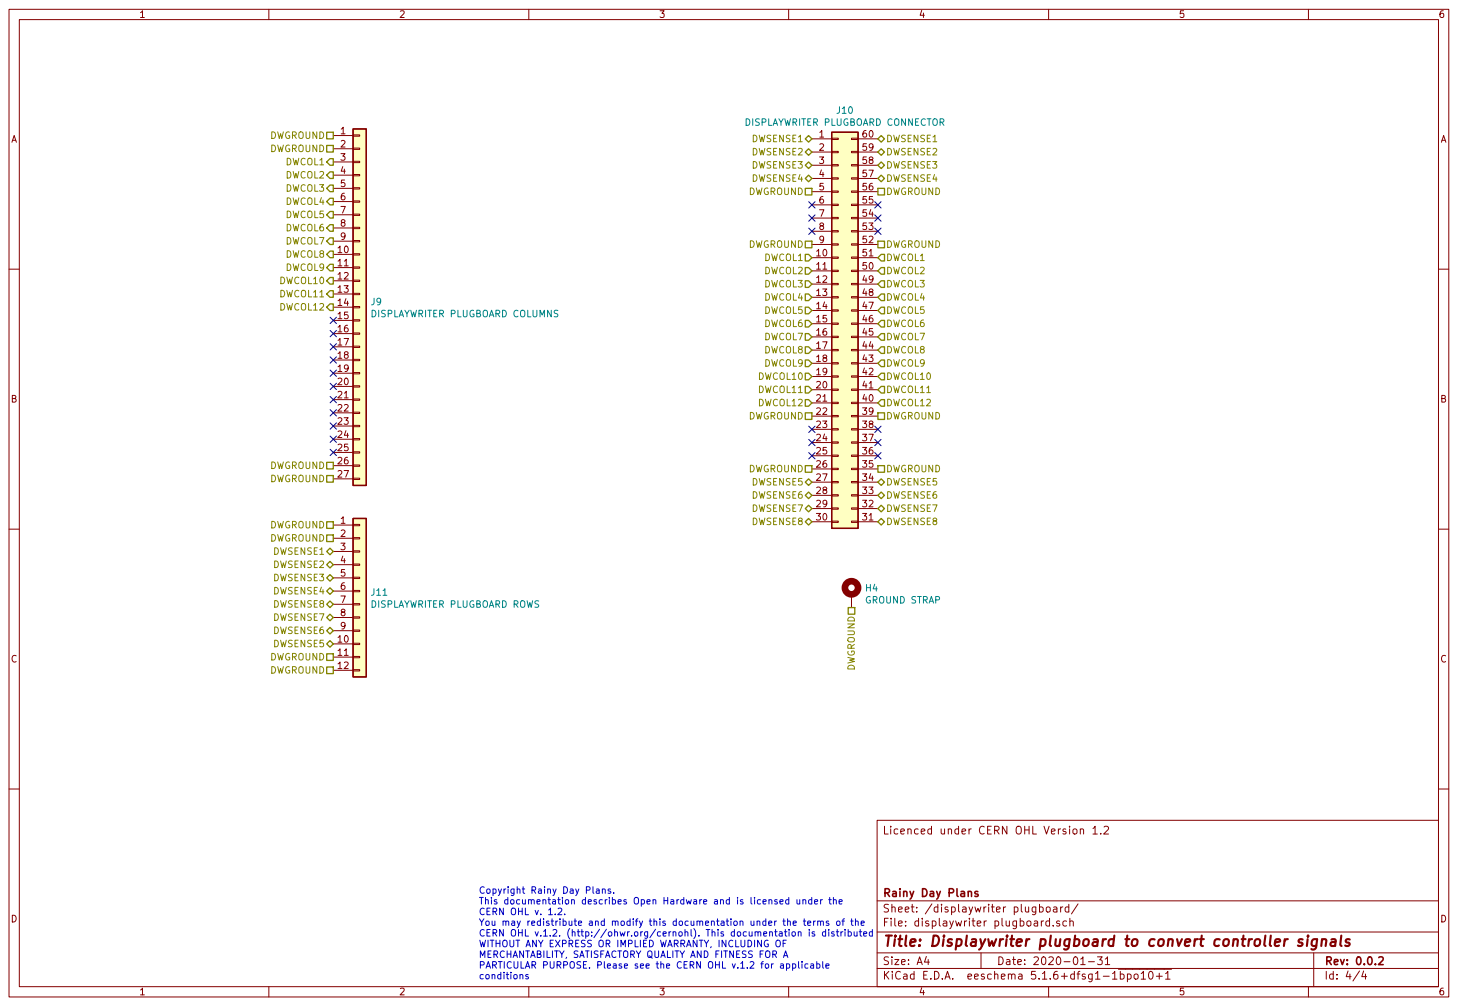
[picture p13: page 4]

Licenced under CERN OHL Version 1.2

Rainy Day Plans
Sheet: /displaywriter plugboard/
File: displaywriter plugboard.sch
Id: 4/4 Title: Displaywriter plugboard to convert controller signals

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

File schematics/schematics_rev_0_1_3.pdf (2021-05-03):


Either mount just the resistor networks,
or mount just the individual pulls to BIAS.

RESET HEADER1_NUMLCK HEADER2_CAPSLCK BIAS BIAS BIAS BIAS BIAS BIAS

File: beamspring plugboard.sch

H1Grounded hole for M3 standoff GNDA

File: displaywriter plugboard.sch

Copyright Rainy Day Plans.
This documentation describes Open Hardware and is licensed under the CERN OHL v. 1.2. You may redistribute and modify this documentation under the terms of the

Id: 1/4 Title: TH-XWhatsIt combined beamspring and model f controller File: TH-XWhatsIt.sch Sheet: / Rainy Day Plans

CERN OHL v.1.2. (http://ohwr.org/cernohl). This documentation is distributed WITHOUT ANY EXPRESS OR IMPLIED WARRANTY, INCLUDING OF MERCHANTABILITY, SATISFACTORY QUALITY AND FITNESS FOR A

PARTICULAR PURPOSE. Please see the CERN OHL v.1.2 for applicable
conditions


Licenced under CERN OHL Version 1.2

Rainy Day Plans
Sheet: /beamspring plugboard/
File: beamspring plugboard.sch
Id: 2/4 Title: Beamspring plugboard to convert controller signals

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


IBM 3178 WIDE PINOUT HERE

Licenced under CERN OHL Version 1.2 1

Rainy Day Plans
Sheet: /model f plugboard/
File: model f plugboard.sch
Id: 3/4 Title: model F plugboard to convert controller signals

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


Licenced under CERN OHL Version 1.2

Rainy Day Plans
Sheet: /displaywriter plugboard/
File: displaywriter plugboard.sch
Id: 4/4 Title: Displaywriter plugboard to convert controller signals

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

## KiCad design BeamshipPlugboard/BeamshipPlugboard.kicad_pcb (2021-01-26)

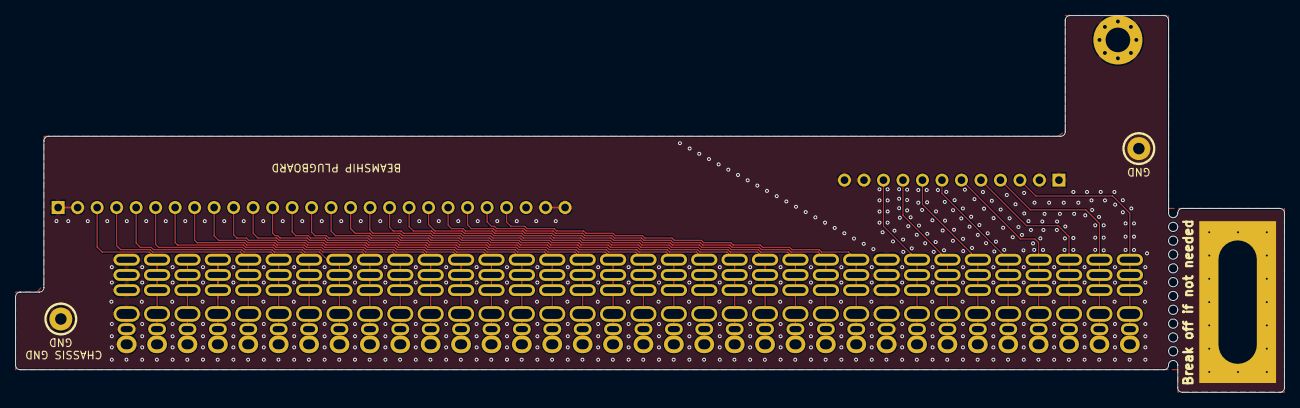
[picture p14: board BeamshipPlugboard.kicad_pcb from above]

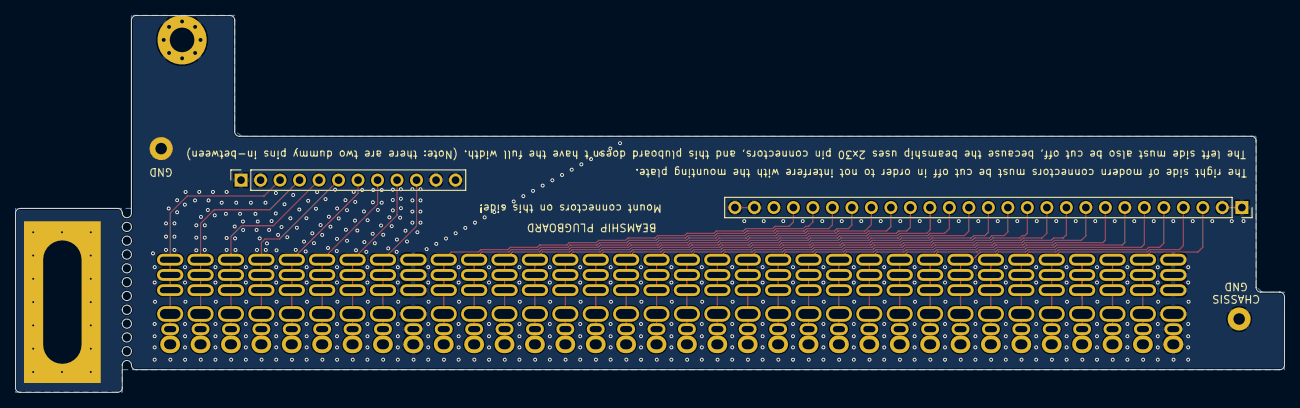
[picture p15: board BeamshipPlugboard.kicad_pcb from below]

Board: 2 copper layers, 165.3 x 49.1 mm, 7 parts (2 on the bottom side), 31 nets.

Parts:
H1: Grounded hole for M3 standoff; MountingHole_3.2mm_M3_Pad_Via
H2: BEAMSHIP MOUNTING HOLE; beamship_mounting_hole
H3, H4: GROUND STRAP; ChassisGnd
J1: BEAMSPRING PLUGBOARD COLUMNS; PinSocket_1x27_P2.54mm_Vertical
J2: BEAMSPRING PLUGBOARD ROWS; PinSocket_1x12_P2.54mm_Vertical
J7: Conn_01x34; beamship_new_2

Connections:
/BSCOL1: J1.3, J7.2
/BSCOL2: J1.4, J7.5
/BSCOL3: J1.5, J7.6
/BSCOL4: J1.6, J7.7
/BSCOL5: J1.7, J7.8
/BSCOL6: J1.8, J7.9
/BSCOL7: J1.9, J7.10
/BSCOL8: J1.10, J7.11
/BSCOL9: J1.11, J7.12
/BSCOL10: J1.12, J7.13
/BSCOL11: J1.13, J7.14
/BSCOL12: J1.14, J7.15
/BSCOL13: J1.15, J7.16
/BSCOL14: J1.16, J7.17
/BSCOL15: J1.17, J7.18
/BSCOL16: J1.18, J7.19
/BSCOL17: J1.19, J7.20
/BSCOL18: J1.20, J7.21
/BSCOL19: J1.21, J7.22
/BSCOL20: J1.22, J7.23
/BSCOL21: J1.23, J7.24
/BSCOL22: J1.24, J7.25
/BSGROUND: H1.1, H2.1, H3.1, H4.1, J1.1, J1.2, J1.26, J1.27, J2.1, J2.2, J2.11, J2.12, J7.1, J7.26
/BSSENSE1: J2.10, J7.27
/BSSENSE2: J2.9, J7.28
/BSSENSE3: J2.8, J7.29
/BSSENSE4: J2.7, J7.30
/BSSENSE5: J2.6, J7.31
/BSSENSE6: J2.5, J7.32
/BSSENSE7: J2.4, J7.33
/BSSENSE8: J2.3, J7.34

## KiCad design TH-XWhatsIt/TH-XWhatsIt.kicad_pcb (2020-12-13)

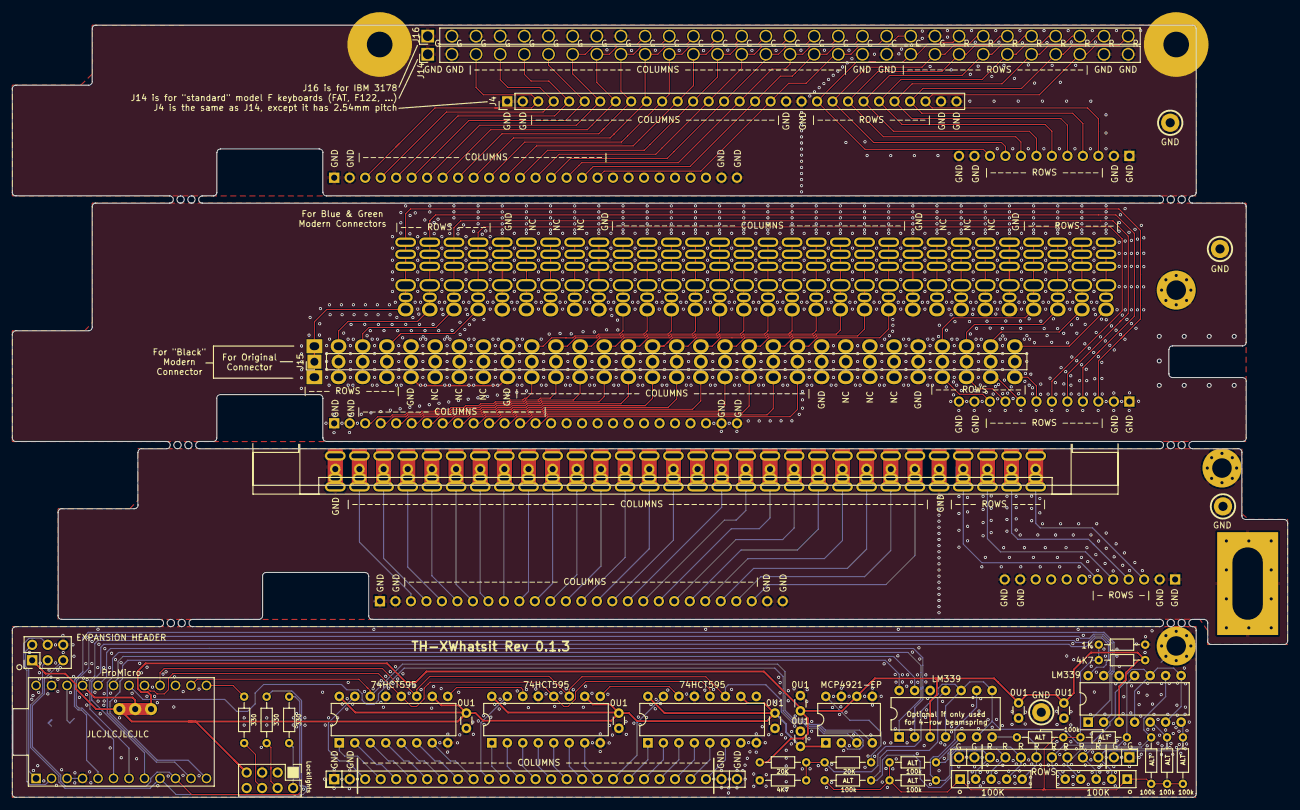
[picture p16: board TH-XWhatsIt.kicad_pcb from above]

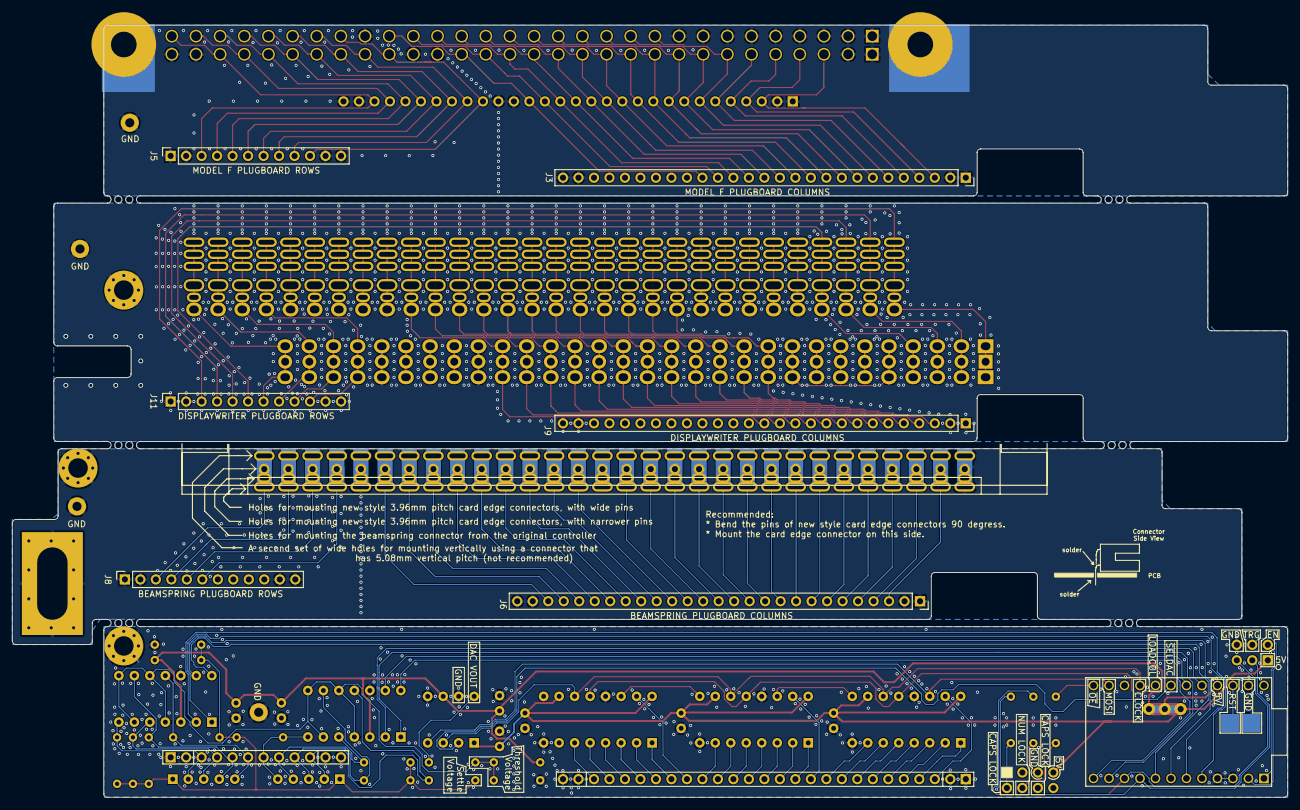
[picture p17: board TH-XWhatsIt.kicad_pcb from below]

Board: 2 copper layers, 209.1 x 126.6 mm, 60 parts (9 on the bottom side), 135 nets.

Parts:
C3, C4, C5, C7, C8, C9, C10: 0U1; C_Disc_D3.0mm_W1.6mm_P2.50mm
H1, H3, H4: Grounded hole for M3 standoff; MountingHole_3.2mm_M3_Pad_Via
H5: Beamspring Mounting Hole; BeamSpringGroundingMountingHoleForTHOnly
H6, H7, H8, H9: Solderable ground strap; ChassisGnd
H10: Left Mountinghole; ModelF_new_mounting_hole_left
H11: Right Mountinghole; ModelF_new_mounting_hole_right
J1: COLUMNS; PinHeader_1x27_P2.54mm_Vertical
J2: ROWS; PinHeader_1x12_P2.54mm_Vertical
J3: MODEL F PLUGBOARD COLUMNS; PinSocket_1x27_P2.54mm_Vertical
J4: MODEL F PLUGBOARD CONNECTOR; PinHeader_1x30_P2.54mm_Vertical
J5: MODEL F PLUGBOARD ROWS; PinSocket_1x12_P2.54mm_Vertical
J6: BEAMSPRING PLUGBOARD COLUMNS; PinSocket_1x27_P2.54mm_Vertical
J7: BEAMSPRING PLUGBOARD CONNECTOR; beamspring_connector_footprint
J8: BEAMSPRING PLUGBOARD ROWS; PinSocket_1x12_P2.54mm_Vertical
J9: DISPLAYWRITER PLUGBOARD COLUMNS; PinSocket_1x27_P2.54mm_Vertical
J10: Conn_01x30; displaywriter-connector_v3
J11: DISPLAYWRITER PLUGBOARD ROWS; PinSocket_1x12_P2.54mm_Vertical
J12: EXPANSION HEADER; PinHeader_2x03_P2.54mm_Vertical
J13: Conn_01x02; PadsToShort
J14, J16: MODEL F PLUGBOARD CONNECTOR; Model_F_3.96mm_pitch_footprint
J15: Conn_01x30; Displaywriter_with_mountinghole_footprint
J17: Locklights; FAT_LockLightsConnector
NT2: Net-Tie_3; NetTie-3_THT_Pad1.0mm_mod_thicker
R1, R5: 4K7; R_Axial_DIN0204_L3.6mm_D1.6mm_P7.62mm_Horizontal
R2: 1K; R_Axial_DIN0204_L3.6mm_D1.6mm_P7.62mm_Horizontal
R3, R4: 20K; R_Axial_DIN0204_L3.6mm_D1.6mm_P7.62mm_Horizontal
R6, R7, R8, R9, R10, R11, R12, R13: 100k; R_Axial_DIN0204_L3.6mm_D1.6mm_P7.62mm_Horizontal
R14, R15, R16: 330; R_Axial_DIN0204_L3.6mm_D1.6mm_P7.62mm_Horizontal
RN1, RN3: 100K; R_Array_SIP5
U1, U6: LM339; DIP-14_W7.62mm
U2: MCP4921-EP; DIP-8_W7.62mm
U3, U5, U8: 74HCT595; DIP-16_W7.62mm
U7: ProMicro

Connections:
+5VA: C4.2, C9.2, C10.2, NT2.3, R1.1, R3.2, U1.3, U2.6, U6.3
+5VD: C3.2, C5.2, C7.2, C8.2, J12.1, J17.7, NT2.1, U2.1, U3.10, U3.16, U5.10, U5.16, U8.10, U8.16
/beamspring plugboard/BSCOL1: J6.3, J7.2
/beamspring plugboard/BSCOL2: J6.4, J7.3
/beamspring plugboard/BSCOL3: J6.5, J7.4
/beamspring plugboard/BSCOL4: J6.6, J7.5
/beamspring plugboard/BSCOL5: J6.7, J7.6
/beamspring plugboard/BSCOL6: J6.8, J7.7
/beamspring plugboard/BSCOL7: J6.9, J7.8
/beamspring plugboard/BSCOL8: J6.10, J7.9
/beamspring plugboard/BSCOL9: J6.11, J7.10
/beamspring plugboard/BSCOL10: J6.12, J7.11
/beamspring plugboard/BSCOL11: J6.13, J7.12
/beamspring plugboard/BSCOL12: J6.14, J7.13
/beamspring plugboard/BSCOL13: J6.15, J7.14
/beamspring plugboard/BSCOL14: J6.16, J7.15
/beamspring plugboard/BSCOL15: J6.17, J7.17
/beamspring plugboard/BSCOL16: J6.18, J7.18
/beamspring plugboard/BSCOL17: J6.19, J7.19
/beamspring plugboard/BSCOL18: J6.20, J7.20
/beamspring plugboard/BSCOL19: J6.21, J7.21
/beamspring plugboard/BSCOL20: J6.22, J7.22
/beamspring plugboard/BSCOL21: J6.23, J7.23
/beamspring plugboard/BSCOL22: J6.24, J7.24
/beamspring plugboard/BSCOL23: J6.25, J7.25
/beamspring plugboard/BSGROUND: H3.1, H5.1, H8.1, J6.1, J6.2, J6.26, J6.27, J7.1, J7.26, J8.1, J8.2, J8.11, J8.12
/beamspring plugboard/BSSENSE1: J7.27, J8.6
/beamspring plugboard/BSSENSE2: J7.28, J8.5
/beamspring plugboard/BSSENSE3: J7.29, J8.4
/beamspring plugboard/BSSENSE4: J7.30, J8.3
/displaywriter plugboard/DWCOL1: J9.3, J10.10, J15.10
/displaywriter plugboard/DWCOL2: J9.4, J10.11, J15.11
/displaywriter plugboard/DWCOL3: J9.5, J10.12, J15.12
/displaywriter plugboard/DWCOL4: J9.6, J10.13, J15.13
/displaywriter plugboard/DWCOL5: J9.7, J10.14, J15.14
/displaywriter plugboard/DWCOL6: J9.8, J10.15, J15.15
/displaywriter plugboard/DWCOL7: J9.9, J10.16, J15.16
/displaywriter plugboard/DWCOL8: J9.10, J10.17, J15.17
/displaywriter plugboard/DWCOL9: J9.11, J10.18, J15.18
/displaywriter plugboard/DWCOL10: J9.12, J10.19, J15.19
/displaywriter plugboard/DWCOL11: J9.13, J10.20, J15.20
/displaywriter plugboard/DWCOL12: J9.14, J10.21, J15.21
/displaywriter plugboard/DWGROUND: H4.1, H9.1, J9.1, J9.2, J9.26, J9.27, J10.5, J10.9, J10.22, J10.26, J11.1, J11.2, J11.11, J11.12, J15.5, J15.9, J15.22, J15.26
/displaywriter plugboard/DWSENSE1: J10.1, J11.3, J15.1
/displaywriter plugboard/DWSENSE2: J10.2, J11.4, J15.2
/displaywriter plugboard/DWSENSE3: J10.3, J11.5, J15.3
/displaywriter plugboard/DWSENSE4: J10.4, J11.6, J15.4
/displaywriter plugboard/DWSENSE5: J10.27, J11.10, J15.27
/displaywriter plugboard/DWSENSE6: J10.28, J11.9, J15.28
/displaywriter plugboard/DWSENSE7: J10.29, J11.8, J15.29
/displaywriter plugboard/DWSENSE8: J10.30, J11.7, J15.30
/model f plugboard/MFCOL1: J3.3, J4.3, J14.3
/model f plugboard/MFCOL2: J3.4, J4.4, J14.4
/model f plugboard/MFCOL3: J3.5, J4.5, J14.5
/model f plugboard/MFCOL4: J3.6, J4.6, J14.6
/model f plugboard/MFCOL5: J3.7, J4.7, J14.7, J16.10
/model f plugboard/MFCOL6: J3.8, J4.8, J14.8, J16.11
/model f plugboard/MFCOL7: J3.9, J4.9, J14.9, J16.12
/model f plugboard/MFCOL8: J3.10, J4.10, J14.10, J16.13
/model f plugboard/MFCOL9: J3.11, J4.11, J14.11, J16.14
/model f plugboard/MFCOL10: J3.12, J4.12, J14.12, J16.15
/model f plugboard/MFCOL11: J3.13, J4.13, J14.13, J16.16
/model f plugboard/MFCOL12: J3.14, J4.14, J14.14, J16.17
/model f plugboard/MFCOL13: J3.15, J4.15, J14.15, J16.18
/model f plugboard/MFCOL14: J3.16, J4.16, J14.16, J16.19
/model f plugboard/MFCOL15: J3.17, J4.17, J14.17, J16.20
/model f plugboard/MFCOL16: J3.18, J4.18, J14.18, J16.21
/model f plugboard/MFGROUND: H7.1, H10.1, H11.1, J3.1, J3.2, J3.26, J3.27, J4.1, J4.2, J4.19, J4.20, J4.29, J4.30, J5.1, J5.2, J5.11, J5.12, J14.1, J14.2, J14.19, J14.20, J14.29, J14.30, J16.1, J16.2, J16.3, J16.4, J16.5, J16.6, J16.7, J16.8, J16.9, J16.22
/model f plugboard/MFSENSE1: J4.21, J5.10, J14.21, J16.23
/model f plugboard/MFSENSE2: J4.22, J5.9, J14.22, J16.24
/model f plugboard/MFSENSE3: J4.23, J5.8, J14.23, J16.25
/model f plugboard/MFSENSE4: J4.24, J5.7, J14.24, J16.26
/model f plugboard/MFSENSE5: J4.25, J5.6, J14.25, J16.27
/model f plugboard/MFSENSE6: J4.26, J5.5, J14.26, J16.28
/model f plugboard/MFSENSE7: J4.27, J5.4, J14.27, J16.29
/model f plugboard/MFSENSE8: J4.28, J5.3, J14.28, J16.30
BIAS: R1.2, R2.1, R6.1, R7.1, R8.1, R9.1, R10.1, R11.1, R12.1, R13.1, RN1.1, RN3.1
CLOCK: U2.3, U3.11, U5.11, U7.16, U8.11
COL1: J1.3, U3.15
COL2: J1.4, U3.1
COL3: J1.5, U3.2
COL4: J1.6, U3.3
COL5: J1.7, U3.4
COL6: J1.8, U3.5
COL7: J1.9, U3.6
COL8: J1.10, U3.7
COL9: J1.11, U5.15
COL10: J1.12, U5.1
COL11: J1.13, U5.2
COL12: J1.14, U5.3
COL13: J1.15, U5.4
COL14: J1.16, U5.5
COL15: J1.17, U5.6
COL16: J1.18, U5.7
COL17: J1.19, U8.15
COL18: J1.20, U8.1
COL19: J1.21, U8.2
COL20: J1.22, U8.3
COL21: J1.23, U8.4
COL22: J1.24, U8.5
COL23: J1.25, U8.6
GND: C3.1, C4.1, C5.1, C7.1, C8.1, C9.1, C10.1, H1.1, H6.1, J1.1, J1.2, J1.26, J1.27, J2.1, J2.2, J2.11, J2.12, J12.6, J13.1, J17.5, R2.2, R5.1, U1.12, U2.5, U2.7, U3.8, U3.13, U5.8, U5.13, U6.12, U7.3, U7.4, U7.23, U8.8, U8.13
HEADER1_NUMLCK: J12.3, R15.1, U7.9
HEADER2_CAPSLCK: J12.5, R14.1, U7.10
HEADER3_ENABLE: J12.2, U7.1
HEADER4_TRIGGER: J12.4, U7.2
HEADER5_SCRLCK: R16.1, U7.13
LOADCOL: U3.12, U5.12, U7.17, U8.12
MOSI: U2.4, U3.14, U7.14
unnamed: J17.2, R14.2
unnamed: J17.4, R15.2
unnamed: J17.6, R16.2
unnamed: R4.2, U2.8
RESET: J13.2, U7.22
ROW1: U1.1, U7.6
ROW2: U1.2, U7.5
ROW3: U1.14, U7.8
ROW4: U1.13, U7.7
ROW5: U6.1, U7.11
ROW6: U6.14, U7.12
ROW7: U6.2, U7.20
ROW8: U6.13, U7.19
SENSE1: J2.3, R6.2, RN1.2, U1.7
SENSE2: J2.4, R12.2, RN1.3, U1.5
SENSE3: J2.5, R8.2, RN1.4, U1.9
SENSE4: J2.6, R7.2, RN1.5, U1.11
SENSE5: J2.7, R9.2, RN3.5, U6.7
SENSE6: J2.9, R11.2, RN3.3, U6.9
SENSE7: J2.8, R13.2, RN3.4, U6.5
SENSE8: J2.10, R10.2, RN3.2, U6.11
SERIALOUT1: U3.9, U5.14
SERIALOUT2: U5.9, U8.14
SETPOINT: R3.1, R4.1, R5.2, U1.4, U1.6, U1.8, U1.10, U6.4, U6.6, U6.8, U6.10
VCC: NT2.2, U7.21
~SELECTDAC: U2.2, U7.18

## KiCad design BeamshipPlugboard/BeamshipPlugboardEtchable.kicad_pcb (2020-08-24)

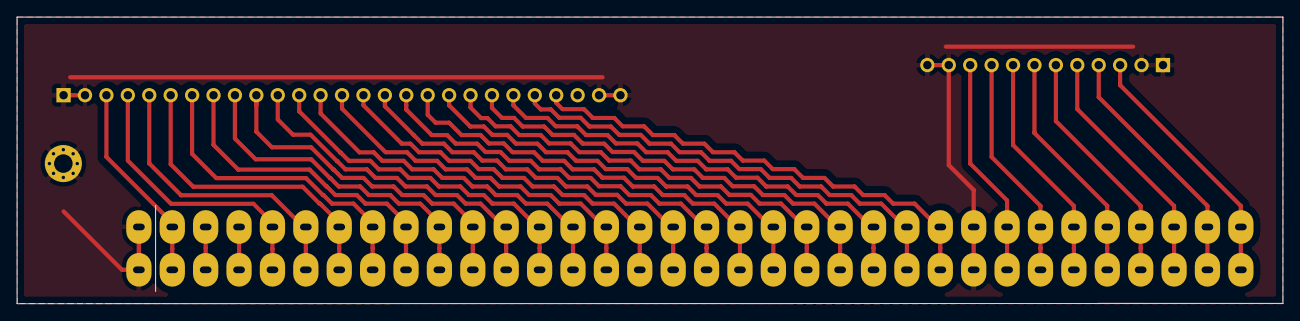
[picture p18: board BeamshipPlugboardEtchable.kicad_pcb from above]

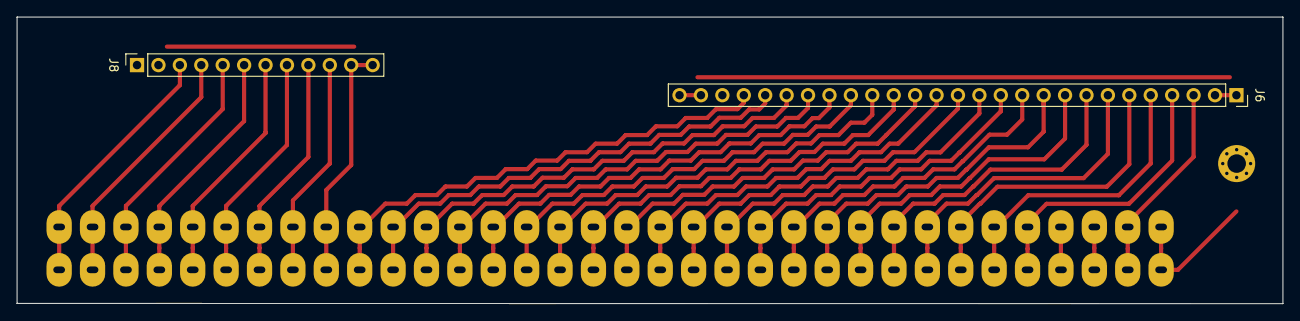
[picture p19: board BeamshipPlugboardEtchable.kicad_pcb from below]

Board: 2 copper layers, 150.1 x 34.0 mm, 4 parts (2 on the bottom side), 31 nets.

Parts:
H3: GROUND STRAP; MountingHole_2.2mm_M2_Pad_Via
J6: BEAMSPRING PLUGBOARD COLUMNS; PinSocket_1x27_P2.54mm_Vertical
J7: Conn_01x34; cardedge_beamship
J8: BEAMSPRING PLUGBOARD ROWS; PinSocket_1x12_P2.54mm_Vertical

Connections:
/beamspring plugboard/BSCOL1: J6.3, J7.2
/beamspring plugboard/BSCOL2: J6.4, J7.5
/beamspring plugboard/BSCOL3: J6.5, J7.6
/beamspring plugboard/BSCOL4: J6.6, J7.7
/beamspring plugboard/BSCOL5: J6.7, J7.8
/beamspring plugboard/BSCOL6: J6.8, J7.9
/beamspring plugboard/BSCOL7: J6.9, J7.10
/beamspring plugboard/BSCOL8: J6.10, J7.11
/beamspring plugboard/BSCOL9: J6.11, J7.12
/beamspring plugboard/BSCOL10: J6.12, J7.13
/beamspring plugboard/BSCOL11: J6.13, J7.14
/beamspring plugboard/BSCOL12: J6.14, J7.15
/beamspring plugboard/BSCOL13: J6.15, J7.16
/beamspring plugboard/BSCOL14: J6.16, J7.17
/beamspring plugboard/BSCOL15: J6.17, J7.18
/beamspring plugboard/BSCOL16: J6.18, J7.19
/beamspring plugboard/BSCOL17: J6.19, J7.20
/beamspring plugboard/BSCOL18: J6.20, J7.21
/beamspring plugboard/BSCOL19: J6.21, J7.22
/beamspring plugboard/BSCOL20: J6.22, J7.23
/beamspring plugboard/BSCOL21: J6.23, J7.24
/beamspring plugboard/BSCOL22: J6.24, J7.25
/beamspring plugboard/BSGROUND: H3.1, J6.1, J6.2, J6.26, J6.27, J7.1, J7.26, J8.1, J8.2, J8.11, J8.12
/beamspring plugboard/BSSENSE1: J7.27, J8.10
/beamspring plugboard/BSSENSE2: J7.28, J8.9
/beamspring plugboard/BSSENSE3: J7.29, J8.8
/beamspring plugboard/BSSENSE4: J7.30, J8.7
/beamspring plugboard/BSSENSE5: J7.31, J8.6
/beamspring plugboard/BSSENSE6: J7.32, J8.5
/beamspring plugboard/BSSENSE7: J7.33, J8.4
/beamspring plugboard/BSSENSE8: J7.34, J8.3

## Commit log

2020-02-04 version bump to 2.0 due to header position changes finished wiring up most of the plugboards, but displaywriter as per usual is the most annoying.....see changes file for more details (jan 3rd, 2020)
    [TH-XWhatsIt.kicad_pcb, TH-XWhatsIt.sch, beamspring plugboard.sch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]
2020-02-04 finished wiring the dispalywriter plugboard, and added grounding straps to plugboards
    [TH-XWhatsIt.kicad_pcb, beamspring plugboard.sch, displaywriter plugboard.sch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]
2020-05-25 Adding BOM and GERBER files for PCB production as 10t8or agreed with kmnov
    [Gerber_BoardOutline.GKO, Gerber_BottomLayer.GBL, Gerber_BottomSilkLayer.GBO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]
2020-07-07 rumors of my demise are greatly exaggerated, updates; more incoming now powered with new pc! thanks for being patient, please inform of futher changes!
    [TH-XWhatsIt.kicad_pcb, TH-XWhatsIt.sch, beamspring plugboard.sch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]
2020-08-22 Removed outdated gerber files
    [Gerber_BoardOutline.GKO, Gerber_BottomLayer.GBL, Gerber_BottomSilkLayer.GBO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]
2020-08-22 Get rid of the rescue library
    [TH-XWhatsIt.sch]
2020-08-22 Removed BOM. I can't seem to regenerate this format and keep it up to date, so removing it, since it's out-of-date
    [TH-XWhatsIt_BOM.csv]
2020-08-22 Removed pull-ups from LM339 outputs. These will be provided in the atmega from now on.
    [TH-XWhatsIt.kicad_pcb, TH-XWhatsIt.sch]
2020-08-22 Fixed missing connection to ground strap
    [TH-XWhatsIt.kicad_pcb]
2020-08-22 Remove extra biasing resistors. Better for >4row keyboards.
    [TH-XWhatsIt.kicad_pcb, TH-XWhatsIt.sch]
2020-08-22 Made DAC output resistors horizontal
    [TH-XWhatsIt.kicad_pcb, TH-XWhatsIt.sch]
2020-08-22 Add option to use individual resistors to pull towards bias
    [TH-XWhatsIt.kicad_pcb, TH-XWhatsIt.sch]
2020-08-22 Renamed schematic title form THT-Xwhatsit to TH xwhatsit, bumped revision to 0.0.3, added revision to silkscreen, added changelog
    [TH-XWhatsIt.kicad_pcb, TH-XWhatsIt.sch]
2020-08-23 Added pads to short reset on bottom
    [TH-XWhatsIt.kicad_pcb, TH-XWhatsIt.sch]
2020-08-23 Use net tie to enforce star ground on the controller
    [TH-XWhatsIt.kicad_pcb, TH-XWhatsIt.sch]
2020-08-23 thicken up ground traces
    [TH-XWhatsIt.kicad_pcb]
2020-08-23 repositioned chips and resistors to make space for beamspring connector
    [TH-XWhatsIt.kicad_pcb]
2020-08-23 I'm just after realizing that this PCB was using the style where the component values are on silkscreen but not the RefDes. Making my changes match this style.
    [TH-XWhatsIt.kicad_pcb, TH-XWhatsIt.sch]
2020-08-23 Made net ties thicker
    [TH-XWhatsIt.kicad_pcb, TH-XWhatsIt.sch]
2020-08-23 Moved top-most resistors tiny bit to the right to potentially accomodate some beamspring connector configurations
    [TH-XWhatsIt.kicad_pcb]
2020-08-23 Added courtyard (measured by me) to pro micro footprint. Removed courtyard from net tie to avoid drc issues. Tweaked net tie clearence type to solid (will help when we add copper fill)
    [TH-XWhatsIt.kicad_pcb]
2020-08-23 beamspring plugboard: use new footprint, and add documentation about how to use it
    [TH-XWhatsIt.kicad_pcb, beamspring plugboard.sch]
2020-08-23 Added big oval mounting hole, Y position not yet final
    [TH-XWhatsIt.kicad_pcb, beamspring plugboard.sch]
2020-08-23 Small bugfix to the PadsToShort footprint, remove paste layer.
    [TH-XWhatsIt.kicad_pcb]
2020-08-23 Added beamspring mounting hole
    [TH-XWhatsIt.kicad_pcb, beamspring plugboard.sch]
2020-08-23 model F plugboard: added 3.96 mm connector too
    [TH-XWhatsIt.kicad_pcb, model f plugboard.sch]
2020-08-23 Clarified which type of connector is supported for vertical mounting
    [TH-XWhatsIt.kicad_pcb]
2020-08-23 displaywriter plugboard: Make sure we don't interfere with mounting plate. Add support for different vertical pin pitch connectors. Add support for original connector with mounting slot. Position of 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
    [TH-XWhatsIt.kicad_pcb, displaywriter plugboard.sch]
2020-08-23 Beamship plugboard: added
    [BeamshipPlugboard.kicad_pcb, BeamshipPlugboard.sch]
2020-08-23 Added etchable variant of BeamshipPlugboard
    [BeamshipPlugboardEtchable.kicad_pcb]
2020-08-23 Beamship plugboard: fix orientation of text
    [BeamshipPlugboard.kicad_pcb]
2020-08-23 Added some notes to beamspring plugboard
    [BeamshipPlugboard.kicad_pcb]
2020-11-01 Various changes to revision 0.1.1
    General:
    Made mounting hole bigger (M3). And moved it a little bit so it doesn't interfere with some components.
    Star ground turned into single ground.
    Ground fills added everywhere.
    Many stitching vias added everywhere.
    Added JLCJLCJLCJLC magic string under pro micro. When ordering from JLCPCB, you can select for Order Number: "Specify Location"
    Bumped version number to 0.1.1
    Added silkscreen to mark rows/columns everywhere.
    Added optional holes for soldering grounding wires everywhere.
    Controller:
    Added silkscreen to ease debugging, by marking various important nets.
    Rearranged some traces to maintain better separati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
    [BeamshipPlugboard.kicad_pcb, BeamshipPlugboard.sch, TH-XWhatsIt.kicad_pcb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]
2020-11-01 beamship: hid away leaking silkscreen
    [BeamshipPlugboard.kicad_pcb]
2020-11-01 Beamship: fix which side of the mounting hole has no solder mask
    [BeamshipPlugboard.kicad_pcb]
2020-11-07 fix up revision in title block on pcb file. (silkskreen already had the correct revision)
    [TH-XWhatsIt.kicad_pcb]
2020-11-07 Added BOM, ERRATA, and PCB_ORDERING_INSTRUCTIONS in markdown format
2020-11-15 BOM updated:
    changed TME examples from carbon film resistors to metal film resistors
    recommendation that 100k resistors/resistor networks should be high precision.
    added LCSC examples
    added Aliexpress M3 standoff/screw/nut/washer/... kit
2020-11-15 BOM: updates(2)
    - reformatted some links
    - added Digi-Key bom items
    - added Mouser bom items
    - added link to OctoPart bom
2020-11-15 BOM: added tme bom csv and guide how to upload
    [tme_bom.csv]
2020-12-13 Made left side of all plugboards 1.5mm shorter (the cutout for the solenoid header is 1.5mm bigger)
    this makes some connectors fit more comfortably
    [TH-XWhatsIt.kicad_pcb, TH-XWhatsIt.sch]
2020-12-13 Added locklights header, bumped revision
    [BeamshipPlugboard.kicad_pcb, TH-XWhatsIt.kicad_pcb, TH-XWhatsIt.sch]
2020-12-13 Updated gerbers
2020-12-13 Updated BOM, changelog, and fixes CHANGES.txt to include accurate date for latest revision
2021-01-26 Beamship Plugboard: added extra grounding hole.
    [BeamshipPlugboard.kicad_pcb, BeamshipPlugboard.sch]
2021-05-03 Updated pro micro schematic symbol, with corrected pin names, and more verbose. No design change.
    [TH-XWhatsIt.sch]
2021-05-03 Added schematics for various revisions. (Using the corrected pro micro symbol), and updated errata.
2021-09-25 Move gerbers.zip into its own folder
